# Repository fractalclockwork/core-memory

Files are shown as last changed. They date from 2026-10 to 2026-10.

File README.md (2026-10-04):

# Core Memory Driver

Electronics for driving and sensing an existing 9″ square ferrite core plane: a 64×64 array (4,096 bits / 512 bytes) with dual-readout edge connectors XA/XB and YA/YB.

Each core is **three-wire** (X, Y, sense)—there is no separate inhibit winding. Sense/inhibit is two independent 2,048-core loops (`YA65`↔`YA66` and `YB65`↔`YB66`). The driver ties `YA66` to `YB65` and reads/drives the outer ends `YA65`/`YB66`; see [docs/theory_of_operation.md](docs/theory_of_operation.md).

## Documentation

Start at [docs/README.md](docs/README.md). Frozen contracts: [docs/icd.md](docs/icd.md). Process layers L0–L4: [docs/reimplementation.md](docs/reimplementation.md). Coverage: [docs/coverage_matrix.md](docs/coverage_matrix.md).

## KiCad

Schematic and PCB live under [kicad/core/](kicad/core/). Custom symbols and card-edge footprints are in [kicad/libs/](kicad/libs/); generators are in [kicad/scripts/](kicad/scripts/). Steer fabric: `steer_64.kicad_sch` (octal tiles: [docs/hierarchy_abi.md](docs/hierarchy_abi.md)).

## Python tooling

Dependencies (e.g. [kiutils](https://pypi.org/project/kiutils/)) are managed with [uv](https://github.com/astral-sh/uv):

```bash
uv sync
uv run python kicad/scripts/gen_pipeline.py              # SPICE decks + coverage + ABI check
uv run python kicad/scripts/gen_pipeline.py --spice-only # ideal + behavioral decks only
uv run python kicad/scripts/gen_pipeline.py --kicad      # also regen KiCad sheets
uv run python kicad/scripts/gen_pipeline.py --check-abi  # octal tile pin budgets
```

Individual generators (also invoked by the pipeline `--kicad` path):

```bash
uv run python kicad/scripts/gen_xy_drive_page.py   # drive_block + steer_64
uv run python kicad/scripts/gen_xy_decode_page.py  # decode_block
uv run python kicad/scripts/gen_decoupling_pages.py
uv run python kicad/scripts/gen_ferrite_beads_page.py --array 64
uv run python kicad/scripts/gen_core_element_sim.py
```

## Simulation

```bash
kicad/core_element_sim/run_regression.sh          # L0 + L1
kicad/core_element_sim/run_regression.sh --l2     # + L2 e2e ladder
kicad/core_element_sim/run_regression.sh --ideal  # + L3 ideal n×n
```

The core-element model is exercised in [kicad/core_element_sim/](kicad/core_element_sim/). L0 detailed MCE and L3 `ideal_core` are separate — see [docs/core_element_sim.md](docs/core_element_sim.md).

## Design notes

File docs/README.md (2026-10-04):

# Design Documentation

Driver-board documentation for the 64×64 magnetic core plane.

## Reading order

1. [Interface control document (ICD)](icd.md) — frozen plane / CCS / enable contract
2. [Reimplementation process (L0–L4)](reimplementation.md) — single core → ideal n×n → fabric
3. [Coverage matrix](coverage_matrix.md) — schematic vs SPICE vs SIL vs bench (do not conflate)
4. [Hierarchical fabric ABI](hierarchy_abi.md) — steer/magnetic pin budgets and octal tiles
5. [Design review](design_review.md) — process retrospective
6. [Signal naming](naming.md) — net taxonomy, block ABI, hierarchy scale path
7. [Theory of operation](theory_of_operation.md) — how a bit is read and written
8. [Major regions](regions.md) — functional circuit blocks on the schematic
9. [Implementation summary](implementation_summary.md) — present schematic state + parts used
10. [Design choices](design_choices.md) — architecture rationale and open decisions
11. [Component selection](component_selection.md) — parts and why they were chosen
12. [Design specification](design_spec.md) — normative plane / connector / timing contract
13. [References](references.md) — bibliography and image sources

## Core element model

[Core-element simulation](core_element_sim.md) — L0 `coremem`, L1/L2 2×2 ladder, L3 `ideal_core` n×n. Regression: `kicad/core_element_sim/run_regression.sh`. Pipeline: `uv run python kicad/scripts/gen_pipeline.py`.

## Archives

- [Chip datasheets](datasheets/README.md) — offline PDF vault for selected MPNs
- [App notes](appnotes/) — supporting application notes (e.g. LTC AN13)
- [Images](img/) — photos and annotations of the physical core plane

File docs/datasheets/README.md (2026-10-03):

# Chip Datasheet Archive

Local manufacturer (or distributor-mirror) PDFs for parts used or selected in this design. Prefer these copies for offline work; verify against the vendor site before production spins.

**Policy:** PDFs are archived for private/lab design reference. Check manufacturer redistribution terms before publishing this repository widely.

Related app notes (not chip datasheets): [../appnotes/](../appnotes/).

## Index

| MPN | File | Used in | Source URL | Retrieved |
|-----|---|---|---|---|
| TLV3501 | [tlv3501.pdf](tlv3501.pdf) | Sense comparator | https://www.ti.com/lit/ds/symlink/tlv3501.pdf | 2026-10-02 |
| OPA192 | [opa192.pdf](opa192.pdf) | CCS feedback amp | https://www.ti.com/lit/ds/symlink/opa192.pdf | 2026-10-02 |
| TL431 | [tl431.pdf](tl431.pdf) | CCS voltage reference | https://www.ti.com/lit/ds/symlink/tl431.pdf | 2026-10-02 |
| SN74AHC74 | [sn74ahc74.pdf](sn74ahc74.pdf) | Sense read latch | https://www.ti.com/lit/ds/symlink/sn74ahc74.pdf | 2026-10-02 |
| SN74AHC138 | [sn74ahc138.pdf](sn74ahc138.pdf) | Decode HS (active-low Y) | https://www.ti.com/lit/ds/symlink/sn74ahc138.pdf | 2026-10-02 |
| SN74AHC238 | [sn74ahc238.pdf](sn74ahc238.pdf) | Decode LS (active-high Y) | https://www.ti.com/lit/ds/symlink/sn74ahc238.pdf | 2026-10-02 |
| TC4427A | [tc4427a.pdf](tc4427a.pdf) | Gate drivers (all channels) | https://media.digikey.com/pdf/Data%20Sheets/Microchip%20PDFs/TC4426A,27A,28A.pdf | 2026-10-02 |
| FDS8958A | [fds8958a.pdf](fds8958a.pdf) | X/Y matrix switches | https://media.digikey.com/pdf/Data%20Sheets/Fairchild%20PDFs/FDS8958A.pdf | 2026-10-02 |
| IRLZ44N | [irlz44n.pdf](irlz44n.pdf) | CCS throttle MOSFET | https://media.digikey.com/pdf/Data%20Sheets/International%20Rectifier%20PDFs/IRLZ44N.pdf | 2026-10-02 |
| BAT54S | [bat54s.pdf](bat54s.pdf) | Sense input clamps | https://www.diodes.com/assets/Datasheets/ds11005.pdf | 2026-10-02 |
| SS14 | [ss14.pdf](ss14.pdf) | Matrix steering Schottky (Vishay SS12–SS16 family sheet) | https://www.vishay.com/docs/88746/ss12.pdf | 2026-10-02 |
| Bourns 3296 | [3296.pdf](3296.pdf) | CCS setpoint trimpot | https://www.bourns.com/docs/product-datasheets/3296.pdf | 2026-10-02 |
| 2N7002 | [2n7002.pdf](2n7002.pdf) | Diagnostic LED buffers | https://media.digikey.com/pdf/Data%20Sheets/Fairchild%20PDFs/2N7002.pdf | 2026-10-02 |
| Keystone 5000-series | [keystone_5000.pdf](keystone_5000.pdf) | Loop test points | https://www.keyelco.com/userAssets/file/M65p27.pdf | 2026-10-02 |

## Not archived

| Item | Reason |
|---|---|
| 2512 1 Ω sense resistor | Commodity passive; no useful IC datasheet |
| 0805 LEDs | Commodity passive |
| AOD4184 | Alternate to IRLZ44N; not primary CCS part |

Part roles and selection rationale: [../component_selection.md](../component_selection.md).

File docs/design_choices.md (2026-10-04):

# Design Choices

Architecture decisions and tradeoffs for the core-plane driver. Part-level picks are in [component_selection.md](component_selection.md). Net grammar, hierarchical block ABI, and the bus / Replicate Layout scale path: [naming.md](naming.md).

## Three-wire cores: no separate inhibit winding

Each core carries **X**, **Y**, and **sense** only (classic 3-wire). There is no fourth inhibit wire through the array. WRITE-0 inhibit reuses the sense path at high current; READ uses the same path as a millivolt differential. That time-multiplex forces Sense-block isolation (1 kΩ), clamps, and soft center-tap bias before Inhibit can source `YA65` and sink `YB66` into the CCS.

## Series differential sense (shared READ / inhibit loops)

The plane has two independent sense/inhibit loops (`YA65`↔`YA66` and `YB65`↔`YB66`), 2,048 cores each. The driver joins them with an external center-tap jumper **`YA66`═`YB65`** and uses the outer ends (`YA65`/`YB66`) as a differential pair. That rejects common-mode drive noise that would swamp a single-ended pickup, and it keeps a single TLV3501 and a single inhibit driver. A dedicated sense-only winding is not available on this hardware, so the driver must protect and bias this shared path for both READ (small-signal) and INHIBIT (high current).

Each loop’s DCR and inductance are half of a continuous 4,096-core weave. Wiring the loops in series presents that full-array L and DCR to the driver, so \(V_{drive}\) and the CCS current stay at \(I_c/2\).

If the series-loop noise floor is too high on the bench, the deferred alternative is to drive and sense the loops in parallel: `YA65` and `YB65` both fed from the inhibit P-FET, `YA66` and `YB66` both returned to `CCS_INH` (that sink then takes \(I_c\), and \(V_{drive}\) can be lower), plus a second TLV3501 whose output is OR’d with the first. That is not the 2×2 sim fixture or the initial 8×8 build.

## Steering diodes on the driver board

The core PCB has no discrete diodes on the drive lines. Without Schottky steering at the matrix outputs, unselected lines form sneak paths that steal current and disturb half-select margins. Diodes belong on the driver board at the matrix outputs (SS14/SS16 class), not as a plane rework.

## 8×8 half-select matrix vs 64 line drivers

Driving 64 X and 64 Y lines with one switch each would explode MOSFET and connector fan-out. Grouping each axis into 8 high-side and 8 low-side switches (with direction for READ vs WRITE) yields an 8×8 coincident-current matrix: twelve address bits total, eight 3-to-8 decoders (FWD×4 + REV×4), and a compact FDS8958A-based switch farm. Cost is more careful sequencing and mandatory steering diodes.

## Prototype 1×1 before scaling lines

Bring-up proves a full READ → STROBE → INHIBIT → WRITE cycle on the 2×2 before trusting n×n SIL. Drive is one hierarchical page [`drive_block.kicad_sch`](../kicad/core/drive_block.kicad_sch): a TC4427A (HS+LS) plus one FDS8958A, with switch-node pins `N_HS_OUT` / `N_LS_OUT`. The SS14s are on [`steer_64.kicad_sch`](../kicad/core/steer_64.kicad_sch) (octal tiles next — [hierarchy_abi.md](hierarchy_abi.md)). Decode is one hierarchical page [`decode_block.kicad_sch`](../kicad/core/decode_block.kicad_sch): one axis = 74AHC138 HS + 74AHC238 LS (`ADDR_NH/NL`, `N_HS{0..7}_n`, `N_LS{0..7}_en`; line# = 8·HS + LS). Root places four decode calls and **32** drive calls (groups 0–7, X/Y, FWD/REV). REV binds `BANK_EN`←`REV_EN_n` and remaps outs to `*r_*`. Scale gates: [reimplementation.md](reimplementation.md).

## Soft mid-bias and input clamps on sense

During inhibit, the outer ends see large excursions. BAT54S clamps dump spikes into the rails; a soft resistive bias from the center tap (`YA66`/`YB65`) to AGND keeps the comparator inputs from floating between cycles. Isolation resistors (e.g. 1 kΩ in Sense) limit clamp current into the amp (~8 mA into clamps at 12 V). This favors a modern fast comparator (TLV3501) over older ±supply parts that assumed different front-ends.

A 1:1 pulse-transformer sense front-end was considered and **deferred**: on this 3-wire plane the same fold ends carry series inhibit, so a low-DCR primary across those pins would shunt inhibit current around the cores. AC-coupling the primary would still slam inhibit edges onto the secondary and force clamps/blanking, erasing the BOM win. DC-coupled Sense stays.

## Manual TL431 + trimpot CCS

Bench bring-up needs a knob for \(I_c/2\) while probing cores of uncertain coercivity (400–800 mA full-select estimate). A TL431 reference and multi-turn 3296W divider set the OPA192 target without firmware or a DAC. A later digital setpoint (DAC or PWM + filter) can replace the trimpot once the operating current is known; the MOSFET + sense-resistor power stage stays.

## AHC logic and TC4427A level shift

The timing controller is 3.3 V (RP2040). Matrix gates need fast, hard \(V_{drive}\) edges. 74AHC138/238 accept 3.3 V inputs with short propagation delay; TC4427A dual non-inverting drivers supply ampere-class gate current from the drive rail so FDS8958A switches cleanly in tens of nanoseconds. Low-side decode uses 74AHC238 (active-high) so every gate driver can be TC4427A — TC4426A is not stocked.

FWD vs REV steering uses duplicated decoder banks gated by `FWD_EN_n` / `REV_EN_n`. That removes a mux layer and keeps fail-safe behavior native (disabled 138 → HIGH → P off; disabled 238 → LOW → N off).

## RP2040 PIO for timing

READ → strobe → inhibit → WRITE needs fixed delays on the order of hundreds of nanoseconds. Main-CPU GPIO toggling under an OS or interrupt load introduces jitter that corrupts sense windows. PIO state machines give cycle-accurate multi-pin sequences while application code runs elsewhere. Another MCU with equivalent programmable I/O could substitute; the requirement is hardware sequencing, not the Pico brand.

## Decisions still open

| Topic | Notes |
|---|---|
| Exact \(I_c\) / \(I_c/2\) setpoint | Characterize on the real plane; trimpot covers 200–400 mA half-select for now |
| \(V_{drive}\) rail voltage | Must satisfy MOSFET gate drive, diode drops, and inductive headroom; value not frozen |
| Inhibit polarity vs READ | Source is `YA65` and sink is `YB66`; whether that direction matches the core’s read polarity is still a bench question |
| Inhibit switch topology | Discrete path vs reuse of matrix/CCS resources |
| On-board vs off-board RP2040 | Pico header vs soldered MCU vs external timing pod |
| Final CCS throttle MOSFET | IRLZ44N in CCS; AOD4184 (or similar) remains a thermal/package alternate |
| Diagnostic LED set | Planned on decoder outputs and DOUT; not yet on the schematic |

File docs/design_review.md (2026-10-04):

# Design review (process retrospective)

Short record of what worked and what to change. Full process: [reimplementation.md](reimplementation.md). ICD: [icd.md](icd.md).

## Verdict

The project succeeded as a **physics-and-architecture discovery engine** through the 2×2 end-to-end ladder (three CCS sinks, series fold, address→DOUT). It struggled as a **scalable productization engine**: detailed MCE was pushed toward 64×64 before an idealized array model existed; hierarchical pin explosion at steer↔plane was discovered late; generators and docs diverged; “full plane in KiCad” was conflated with “full plane in SPICE.”

## What went well

1. **Isolated MCE** before the array — reusable ~35 mV / ~1 µs contract.
2. **Single-CCS FAIL deck** — proved coincident full-select needs three sinks.
3. **Fidelity ladder** on fixed 2×2 weave — oracle → drive → matrix → inhibit → sense → e2e → strobe.
4. **Dual-loop fold archaeology** — soft mid, series inhibit on sense ends.
5. **Drive/decode block ABI** — FETs and decoders compressed correctly.
6. **Shared weave math** — `mce_array.py` as seed of one AST for sch + sim.

## What went wrong

1. Scaled detailed `coremem` instead of introducing an **idealized core** first.
2. **Pin explosion** at 256 plane ends (320-pin steer, 258-pin magnetic) designed late.
3. **Generators evolved in place** (stage1–8 → live scripts); scale names lagged (`steer_2x2`).
4. **Docs claimed bank coverage** the sim did not exercise; schematic ≠ SPICE ≠ bench.
5. Late freeze of plane topology / core-size disclaimer.
6. Missing L/DCR, PIO SIL, decoupling in nets — n×n could only prove coincidence logic.
7. Expanded 4096-MCE schematic before L3 runtime contract existed.

## Carry forward

**Keep:** isolated MCE bench; single-CCS FAIL; block ladder on small n; CCS×3; weave AST; soft fold.

**Change:** idealized core before n>2; hierarchy for 64 lines on day one; one regen pipeline; coverage matrix; separate magnetic schematic from SPICE plant; runtime as a gate.

**Do not repeat:** 4096 detailed MCEs as scale proof; growing `steer_2x2` without rename/ABI redesign; docs implying 64×64 e2e; treating checkerboard sense as traced geography.

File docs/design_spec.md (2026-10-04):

# Magnetic Core Memory Drive and Sense Circuit: Design Specification

Normative plane interface, drive architecture, and timing contract. Narrative context: [theory_of_operation.md](theory_of_operation.md). Citation keys `[cite: 1]` / `[cite: 2]` are defined in [references.md](references.md).

## 1. Physical Parameters & Interface Specification
* **PCB Dimensions:** The magnetic core plane is constructed on a 9-inch square PCB featuring four edge connector interfaces labeled XA, XB, YA, and YB [[cite: 1](references.md#core-plane-physical-evidence)].
* **Connector Type:** Dual-readout staggered edge connector.
* **Contact Dimensions:** Pins are 0.125" wide with a 0.1875" (3/16") center-to-center pitch on each face.
* **Staggered Layout:** Odd-numbered pins are located on the top face [[cite: 1](references.md#core-plane-physical-evidence)], and even-numbered pins are located on the bottom face [[cite: 2](references.md#core-plane-physical-evidence)]. Pin 1 begins 1.3125" (1-5/16") from the right edge, offsetting the top and bottom contacts by exactly 0.0625" to maximize contact area while preventing wiper shorts during insertion.
* **Axis Connectors:**
    * **X-Axis (XA, XB):** 64 pins total. Requires a 32-position, dual-readout staggered receptacle.
    * **Y-Axis (YA, YB):** 66 pins total. Requires a 33-position, dual-readout staggered receptacle.
* **Matrix Capacity:** 64×64 bidirectional drive lines yield exactly 4,096 cores (512 bytes).
* **Pin numbering vs address:** Physical edge contacts are labeled **1–64** (drive) plus Y **65/66** (sense). Schematic and firmware address drive lines **0–63**. Mapping: physical pin \(p\) ↔ logical index \(p-1\). Pins 65/66 are **not** drive lines and are **not** part of the Drive/Decode hierarchical pin chain — see §1.1 and §2.
* **Dual sense loops:** Pins 65/66 on YA and YB are two independent loops, 2,048 cores each (`YA65`↔`YA66` and `YB65`↔`YB66`). The plane does not join them. Each loop’s DCR and inductance are half of a single weave through all 4,096 cores. The driver ties `YA66`═`YB65` (external center tap) so the series path is `YA65` → Loop A → jumper → Loop B → `YB66`. Series connection restores the full-array L and DCR. [[cite: 1](references.md#core-plane-physical-evidence), [cite: 2](references.md#core-plane-physical-evidence)]

### 1.1 Three naming layers (keep separate)

Normative net grammar, block ABI, buses, and scale path: **[naming.md](naming.md)**. Mixing physical (1–64 / Y 65–66), syntax (`XA0`…, block `N`/`n`), and semantic (drive vs sense/fold) layers is a recurring source of schematic and doc bugs. Drive Block / Decode Block hierarchical pins only cover the matrix — do not extend that chain to 65/66.

## 2. Sense and Inhibit Architecture (Pins 65 & 66)
Each core is a **three-wire** element (X, Y, sense). There is **no separate inhibit winding**; inhibit is series current on the folded sense wire, time-multiplexed with READ.
* **Two loops + external fold:** Loop A `YA65`↔`YA66`; Loop B `YB65`↔`YB66`. Driver jumper **`YA66`═`YB65`**. Outer ends: `YA65` / `YB66`. The 2×2 on Magnetic Cores is the schematic stand-in (one diagonal per loop).
* **Common-Mode Noise Rejection (Read Phase):** A high-speed differential comparator (schematic: TLV3501; see [component_selection.md](component_selection.md)) across `YA65` / `YB66` isolates the millivolt flip spike. Classic techniques: [AN13](appnotes/an13f.pdf).
* **Center-Tap Bias:** Soft-bias the center tap `YA66`/`YB65` (schematic: 10 kΩ → AGND), not a hard AGND short, so inhibit current traverses both loops into the CCS.
* **Series Inhibit Drive (Write Phase):** Source \(V_{drive}\) into `YA65` and sink `YB66` to `CCS_INH` at \(-I_c/2\), so current flows Loop A, crosses `YA66`═`YB65`, and returns through Loop B — all cores in series. A parallel-drive alternative (both loops at once, two comparators) is deferred; see [design_choices.md](design_choices.md).

## 3. Drive Architecture (64x64 Matrix)
* **Matrix Structure:** Group the 64 lines per axis into 8 rows and 8 columns. Implement 8 High-Side source switches and 8 Low-Side sink switches per axis, per direction (Forward for READ, Reverse for WRITE).
* **Address Decoding:** A 12-bit address word seamlessly maps to this geometry. 6 bits decode the X-axis (3 bits for High-Side, 3 bits for Low-Side), and 6 bits decode the Y-axis. Standard 3-to-8 line decoders (74AHC138 HS / 74AHC238 LS; see [component_selection.md](component_selection.md)) control the matrix.
* **Steering Diodes:** Because there are no discrete diodes populated on the memory plane itself [[cite: 1](references.md#core-plane-physical-evidence), [cite: 2](references.md#core-plane-physical-evidence)], fast-recovery Schottky diodes must be placed on the driver board at the output of the switch matrices to prevent back-feeding and "sneak paths" through unselected core lines.

## 4. Current Recommendations ($I_c$)
* **Coercive Current ($I_c$):** Given the 0.125-inch core diameter, expect a full-select current between 400mA and 800mA. A separate single-core study uses an explicit 50-mil toroid at the top of this current band; it does not replace this paragraph. See [core_element_sim.md](core_element_sim.md). 
* **Drive Regulation:** The half-select current ($I_c/2$) of 200mA to 400mA must be strictly regulated on each axis at once. Three copies of the same adjustable constant-current sink: `CCS_X` for the X low-side returns, `CCS_Y` for the Y low-side returns, and `CCS_INH` for the inhibit return. One shared sink splits the coincident pulse and the addressed core never sees full-select. A power op-amp driving an N-channel MOSFET, monitored by a low-ohm sense resistor, holds each path flat despite the inductive load.

## 5. Timing & Sequencing
Core memory operations require sub-microsecond, deterministic pulse sequencing. A READ destroys the data, so every access is a READ / RESTORE cycle.
1. **READ Phase:** Drive $-I_c/2$ into the target X and Y lines. 
2. **SENSE STROBE:** Wait ~150-300ns for capacitive ringing to settle, then clock the D-flip-flop connected to the differential comparator across `YA65` / `YB66`.
3. **INHIBIT Phase:** If writing/restoring a '0', drive $-I_c/2$ from `YA65` through the `YA66`═`YB65` center tap and out `YB66`.
4. **WRITE Phase:** Drive $+I_c/2$ into the target X and Y lines.

Standard software bit-banging will introduce cycle jitter that corrupts memory. Utilizing hardware-level programmable state machines—such as the PIO (Programmable I/O) blocks on an RP2040/Raspberry Pi Pico—driven by tight C or Assembly routines allows for multi-phase sub-microsecond sequence execution with absolute cycle accuracy independent of the main CPU clock.

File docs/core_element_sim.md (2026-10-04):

# Core-Element Simulation

SPICE model of one three-wire memory core. The driver schematic uses it as the MCE (magnetic core element) symbol on [magnetic_core_64x64.kicad_sch](../kicad/core/magnetic_core_64x64.kicad_sch): the same six pins as the old ferrite-bead stand-in, with the flux probe kept inside the `mce` wrapper. The 2×2 page that this model was first woven into is archived at [reference/magnetic_core_2x2.kicad_sch](../kicad/core/reference/magnetic_core_2x2.kicad_sch). This project remains the isolated testbench.

KiCad project: [kicad/core_element_sim/](../kicad/core_element_sim/). Subcircuit: [models/coremem.cir](../kicad/core_element_sim/models/coremem.cir). Batch deck: [models/coremem_tb.cir](../kicad/core_element_sim/models/coremem_tb.cir).

## Why this is not the LTspice Chan `K` statement

KiCad simulates with ngspice. In that engine a `K` line is a linear coupling coefficient. It does not accept the Chan parameters `Hc`, `Br`, `Bs`, `Lm`, and `A` that LTspice puts on a mutual inductor (Chan et al., IEEE Trans. CAD, 1991; see [references.md](references.md)).

Two further limits pushed the model off that formulation:

- Memory squareness here is \(B_r/B_s = 0.18/0.20 = 0.90\). LTspice’s Chan solver is known to stall when that ratio is much above about \(2/3\), especially under one-sided saturation.
- A 20–50 mV sense pulse across a 10–50 Ω damper is only a couple of milliamps. With ideal current sources that resistor does not stretch the flip out to 1 µs. The peaking time is a parameter of the core, `Tsw`.

The subcircuit still takes the same physical numbers. Switching is a domain-wall time: while \(|H| > H_c\), the normalized remanence \(m\) slews toward the driven rail in about `Tsw`, and each winding voltage is Faraday’s law, \(V = A\,dB/dt\), with \(B = B_r m + \mu_0 \mu_r H\) clamped to \(\pm B_s\).

## Geometry and material (50-mil toroid)

This run uses a typical vintage 50-mil core, not the 0.125 in diameter inferred in [design_spec.md](design_spec.md) §4 from the edge-contact width. The plane’s normative full-select band (400–800 mA) is unchanged. The half-select used below, 400 mA, is the top of that band and is the current the coercivity was matched to.

| Quantity | Value | Origin |
|---|---|---|
| Outer / inner diameter | 1.27 mm / 0.76 mm | 50-mil toroid |
| Mean diameter | 1.0 mm | average of OD and ID |
| Magnetic path \(L_m\) | 0.00314 m | \(\pi \times 1.0\,\mathrm{mm}\) |
| Wall × height | 0.255 mm × 0.38 mm | \((OD-ID)/2\), typical height |
| Area \(A\) | \(0.097\times 10^{-6}\,\mathrm{m}^2\) | wall × height |
| \(B_s\), \(B_r\) | 0.20 T, 0.18 T | squareness \(B_r/B_s = 0.90\) |
| \(H_c\) | 150 A/m (about 1.9 Oe) | below full-select, above half-select |
| Turns | 1 on X, Y, and sense | three-wire core |
| `Tsw` | 1 µs | full-select peaking time |
| \(\mu_r\) | 20 | reversible permeability for the disturb |

Ampere’s law on one turn, \(H = I/L_m\):

- Half-select, 400 mA on X only: \(H \approx 127\,\mathrm{A/m}\), under \(H_c\). The core stays at \(+B_r\).
- Full-select, 400 mA on X and on Y: \(H \approx 255\,\mathrm{A/m}\), over \(H_c\). The core flips.

A remanence reversal \(\Delta B = 2 B_r\) through area \(A\) in 1 µs is an average sense voltage of about 35 mV, inside the 20–50 mV band expected for a single core with one sense turn.

## Stimulus

One 18 µs transient, 100 ns edges, X2/Y2/S2 grounded, 20 Ω across X and across Y. The core starts at \(m = +1\) (`tran … uic`).

| Window | Drive | Intended result |
|---|---|---|
| 2–4 µs | \(I_x = -400\,\mathrm{mA}\) | half-select disturb |
| 6–8 µs | \(I_x = I_y = -400\,\mathrm{mA}\) | read 1, \(+B_r \to -B_r\) |
| 10–12 µs | same full-select again | read 0, already at \(-B_r\) |
| 14–16 µs | \(I_x = I_y = +400\,\mathrm{mA}\) | restore to \(+B_r\) |

Open [core_element_sim.kicad_pro](../kicad/core_element_sim/core_element_sim.kicad_pro) and run the simulator; the sheet carries `.tran 20n 18u uic`. Plot `V(S1)` and `V(B)` (1 V on `B` is 1 T). The same deck from the shell:

```bash
ngspice -b kicad/core_element_sim/models/coremem_tb.cir   # RESULT PASS or RESULT FAIL
python3 kicad/core_element_sim/plot_response.py           # plots/coremem_response.png
```

`ngspice` the program is optional. The plot script talks to `libngspice`, which is the library KiCad already uses. Regenerate the sheet with `uv run python kicad/scripts/gen_core_element_sim.py`.

## Comparison with the literature

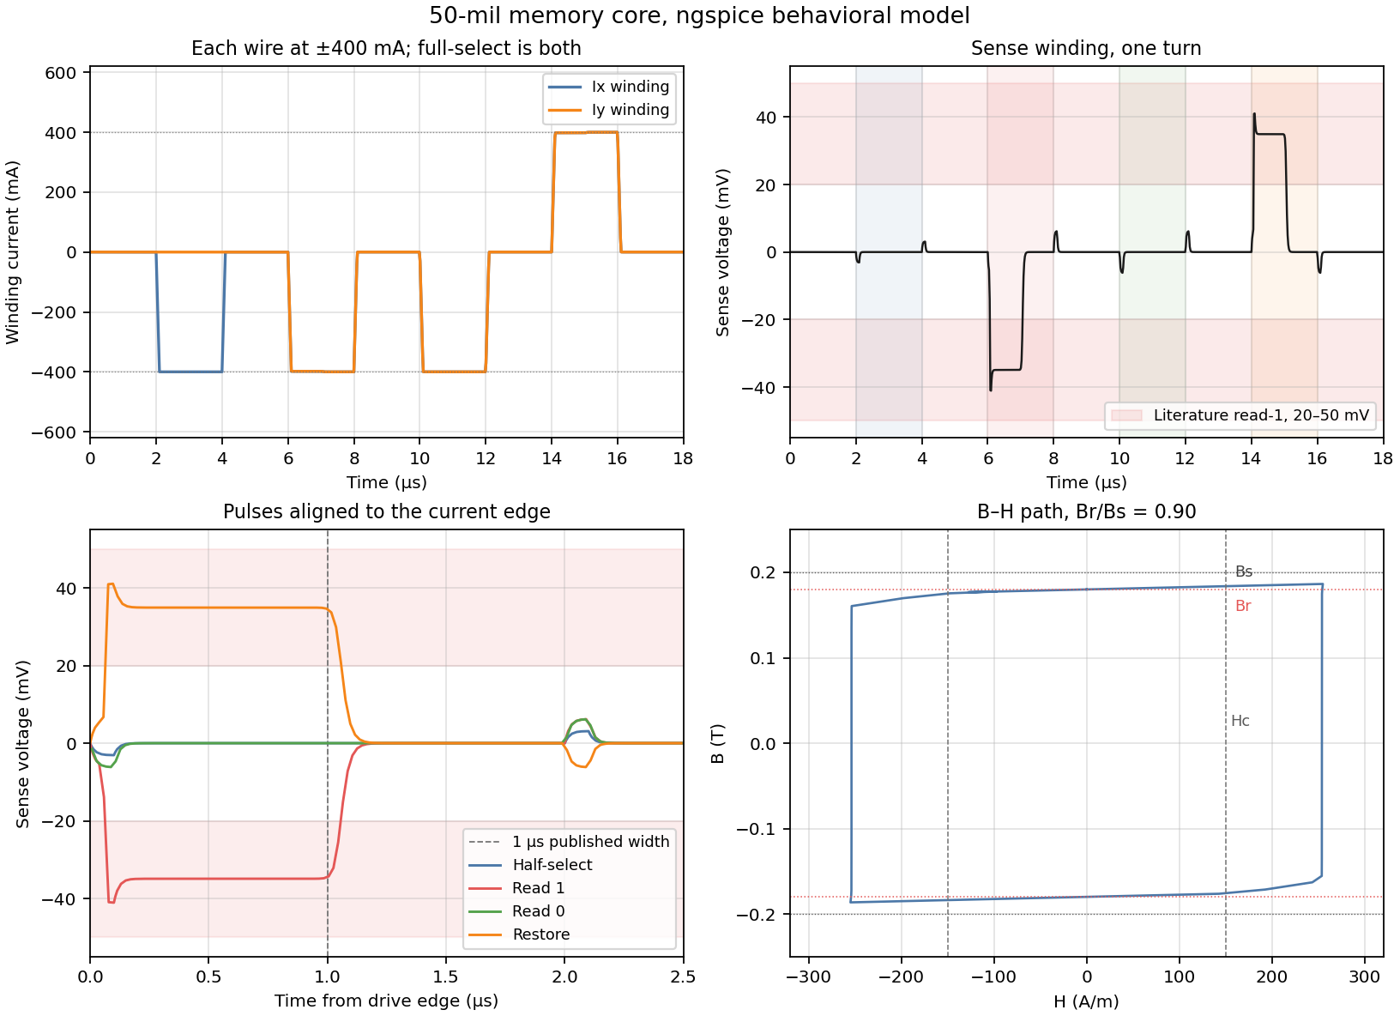
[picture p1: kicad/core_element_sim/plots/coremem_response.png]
Drive, sense, aligned pulses, and B–H path for one 50-mil core.


The pink band on the sense plots is 20–50 mV. The dashed line on the aligned pulses is 1 µs. Both are the single-core targets used to size this model (one sense turn), in the same range as the millivolt, microsecond sense signals of coincident-current practice (Forrester 1951; Papian 1952; Rajchman 1953). They are not a trace digitized from a particular oscilloscope photo.

Numbers from the plot above:

| Event | Sense peak | Width at half amplitude | Remanence after the pulse |
|---|---|---|---|
| Half-select | −3.1 mV | 0.11 µs | stays \(+B_r\) (\(m \approx +1\)) |
| Read 1 | −41 mV | 1.01 µs | flips to \(-B_r\) |
| Read 0 | −6.2 mV | 0.12 µs | stays \(-B_r\) |
| Restore | +41 mV | 1.02 µs | returns to \(+B_r\) |

What lines up with the classic behavior:

- Only the intersection flips. Half-select field stays under \(H_c\), and a second full-select in the same direction does not flip the core again (Rajchman; Papian).
- The read-1 and the restore are tens of millivolts and about 1 µs wide. The read-0 and the half-select disturb are several times smaller, which is the discrimination a sense amplifier needs.
- The B–H path is square, with \(B_r/B_s = 0.90\). \(H_c = 150\,\mathrm{A/m}\) is about 1.9 Oe, in the range memory ferrites were specified in.

Where the waveform is not a scope photo:

Published read-1 pulses are bell-shaped. Menyuk and Goodenough (1955) describe flux reversal whose rate peaks in the middle of the switch, because that is when the domain-wall area is largest. This model slews \(m\) at a nearly constant rate once \(|H| > H_c\), so \(dB/dt\) is flat for about 1 µs. The spikes at the start and end of each current edge are the reversible term \(\mu_0 \mu_r dH/dt\), not the flip. The 20 Ω dampers are on the testbench, as in the original damping note; at these sense voltages they do not set the 1 µs width.

The read-1 peak (−41 mV) is the ~35 mV remanence reversal plus the reversible edge at the start of the ramp. Polarity follows the drive: negative current produces a negative read-1; the restore is the opposite spike.

## 2×2 addressing

The archived 2×2 sheet places four of these cores in the plane’s weave: YA loop through MCE11 and MCE00 (mirrored, top-left to bottom-right), YB loop through MCE10 and MCE01, ends at the XB end of each Y edge, fold `YA66`═`YB65`. The batch deck uses that netlist after the sheet’s `Sim.Pins` map, so current XA→XB and YA→YB both add to H, and current YA65→YB66 opposes a positive write. The live sheet is that weave on a 64×64: `(x+y)` even on YA, odd on YB, 2,048 cores in each loop.

This deck is the single-sink record. The return is one copy of the schematic CCS (`models/ccs.cir`): TL431 at 2.5 V, the 10 kΩ pot set for 400 mA, OPA192, IRLZ44N, and the 1 Ω sense resistor. Selected ends are switched from a 12 V testbench rail; the other end of each driven line, and the inhibit sink, all return through that one node. The schematic does not: X, Y, and inhibit each have their own sink. In the model the op-amp output is held at 2.39 V, just above the gate that regulates 400 mA, so an open return does not wind the MOSFET up to the +5 V rail between pulses.

```bash
ngspice -b kicad/core_element_sim/models/array2x2_tb.cir   # RESULT PASS or RESULT FAIL
python3 kicad/core_element_sim/plot_array.py              # plots/array2x2_response.png
```

One 46 µs transient, cores starting at \(m=+1\). Each pulse is a 1 µs rise, a 2 µs flat, and a 1 µs fall. Read polarity sinks the A end (current B→A). Write sinks the B end. The last window is a write of X1/Y0 with inhibit current also returned through the CCS.

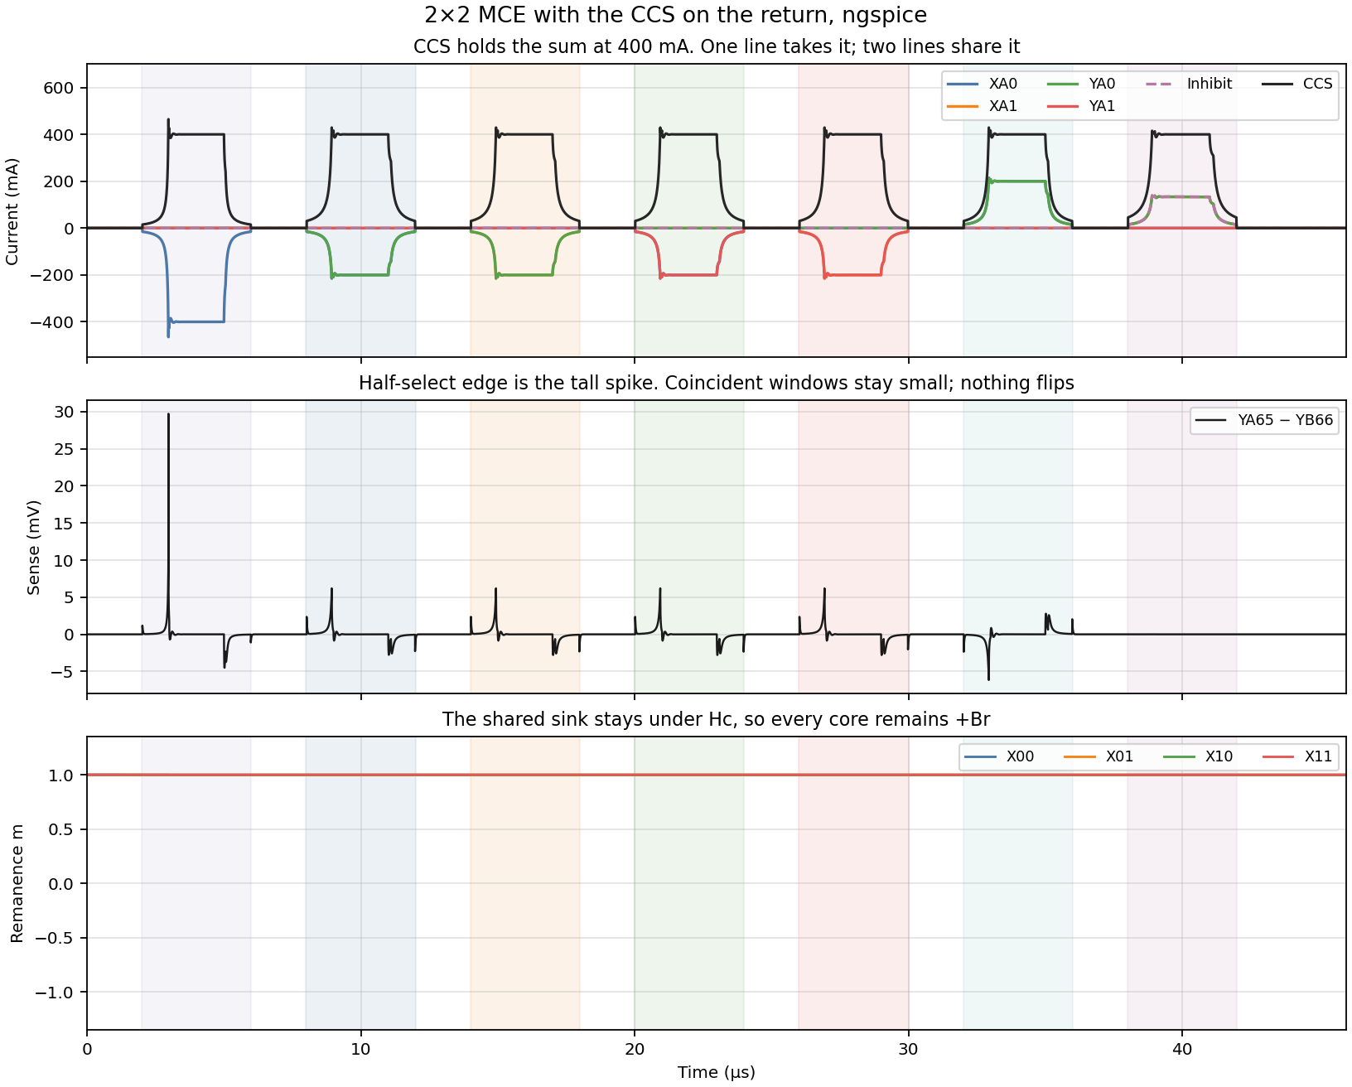
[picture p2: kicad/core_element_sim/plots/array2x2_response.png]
Line currents, series sense, and remanence of the four cores.


What the run checks:

- The sink holds 400 mA on every flat top. A single line carries that whole current. Two lines split it, about 200 mA each. Inhibit is a third path, about 134 mA, and the sum is still 400 mA.
- That split stays under \(H_c\). Half-select, every address window, the restore, and the inhibited write all leave every core at \(+B_r\).
- The half-select edge is a reversible spike of about 30 mV on `YA65`−`YB66`, from the single line taking the full 400 mA. Coincident windows are a few millivolts. Nothing on this string is a flip.

## Read / write-back

One shared sink cannot put 400 mA on X and 400 mA on Y together, so a read cannot flip the addressed core. `array2x2_cycle_tb.cir` keeps the same CCS circuit and gives the X lines, the Y lines, and the inhibit path each their own copy, every one set to 400 mA. That is the schematic: root sheets CCS X, CCS Y, and CCS INH.

All four cores start at \(-B_r\). The run visits X00, then X01, then X10, then X11. Each pulse is a 1 µs rise, a 2 µs flat, and a 1 µs fall. X and Y each have one CCS, shared by the two lines of that axis, and only one of those lines is on at a time. Inhibit has its own CCS.

```bash
ngspice -b kicad/core_element_sim/models/array2x2_cycle_tb.cir   # RESULT PASS or RESULT FAIL
python3 kicad/core_element_sim/plot_cycle.py                     # plots/array2x2_cycle.png
```

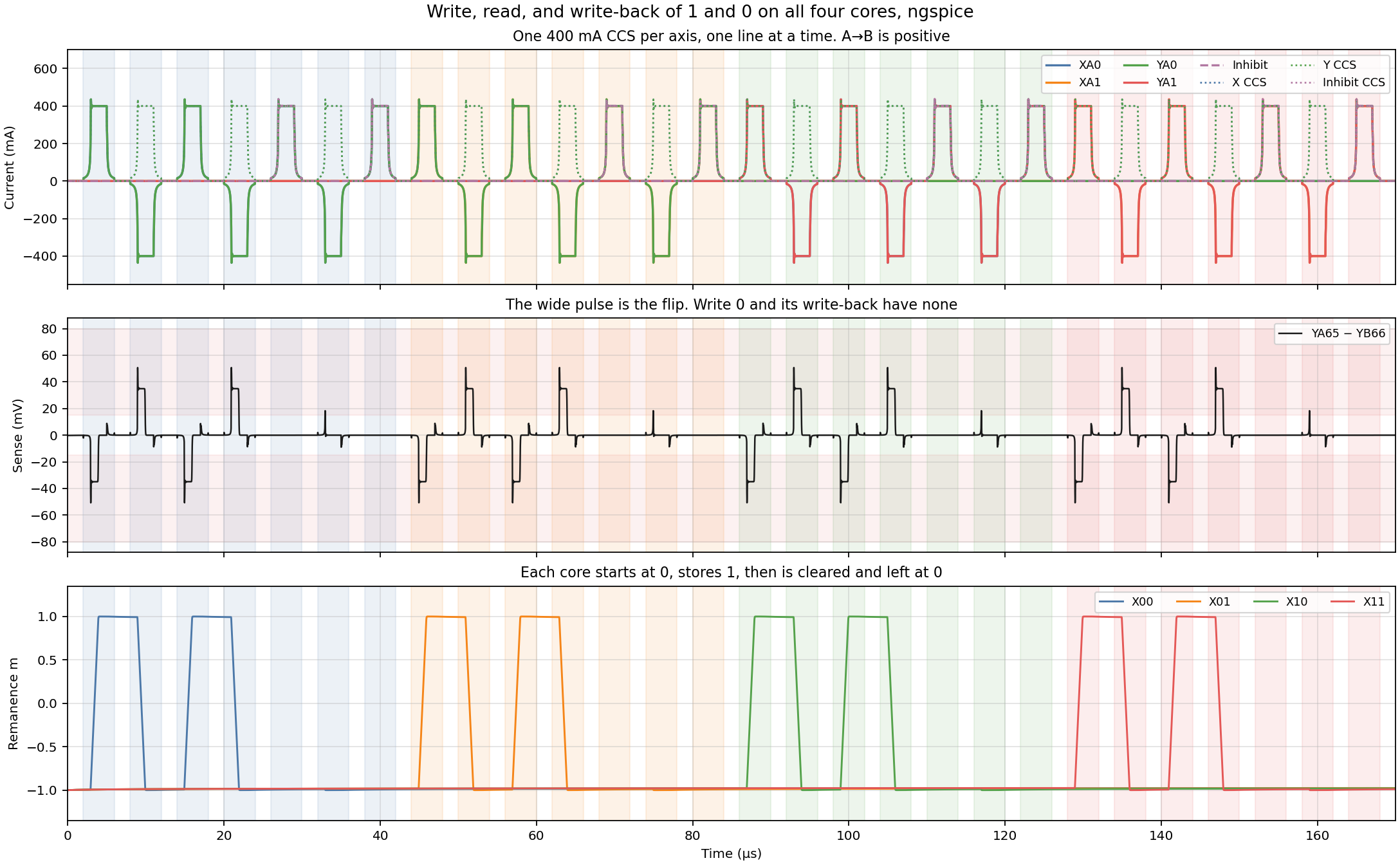
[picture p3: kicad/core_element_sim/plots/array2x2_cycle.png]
Write, read, and write-back of a 1, then of a 0, on all four cores.


What the run checks, on every core:

- Write 1 drives +400 mA on that core’s X line and Y line. The core goes to \(+B_r\). The sense plateau is about −35 mV. The other three cores stay at \(-B_r\).
- Read drives −400 mA on the same two lines. The core goes to \(-B_r\), and the plateau is about +35 mV.
- Write-back drives +400 mA again. The core returns to \(+B_r\).
- Storing a 0 starts with that same read, which clears the 1. The write then adds 400 mA inhibit on YA65→YB66, so the core stays at \(-B_r\) and the plateau collapses. Inhibit current also threads the other three cores and does not flip them.
- Read of that 0 leaves the core at \(-B_r\). The reversible edge is still there; the flip plateau is not. Write-back of the 0 is the inhibited write again, and the core stays at \(-B_r\).

The same cycle is re-run with the real blocks in place of the ideal switches. `array2x2_drive_tb.cir` puts one `drvleg` on X0. `array2x2_matrix_tb.cir` is the diode matrix (shared group-0 high side, low side selects the line). `array2x2_inhibit_tb.cir` and `array2x2_sense_tb.cir` add inhibit and the sense latch. `array2x2_e2e_tb.cir` starts from `ADDR_*`, `DEC_EN`, `FWD_EN_n`, `REV_EN_n`, `INH_EN_n`, and `SENSE_STROBE`.

```bash
ngspice -b kicad/core_element_sim/models/array2x2_e2e_tb.cir   # RESULT PASS or RESULT FAIL
python3 kicad/core_element_sim/plot_e2e.py                     # plots/array2x2_e2e.png
```

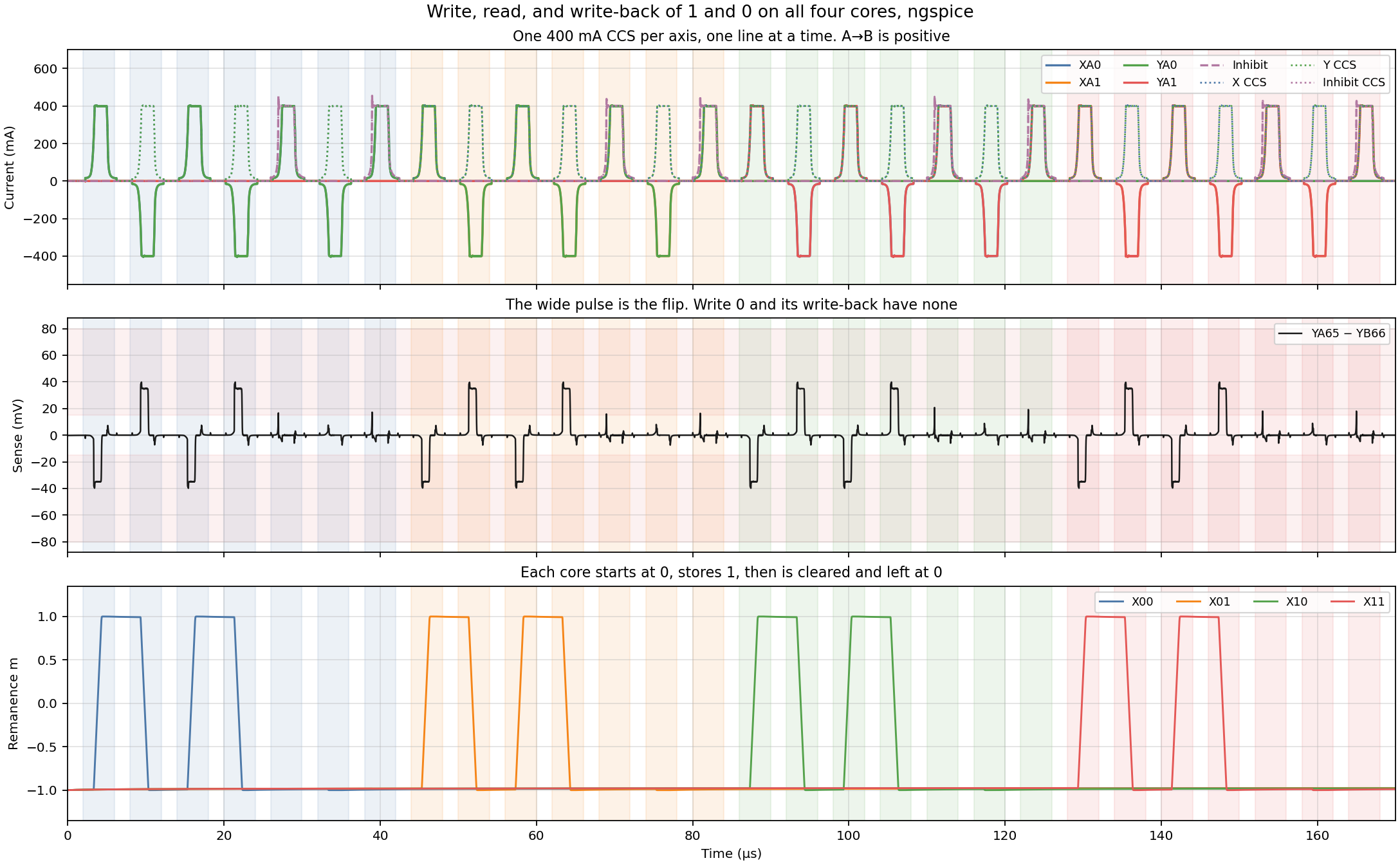
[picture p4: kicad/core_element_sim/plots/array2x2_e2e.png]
The same cycle, started from the address pins.


## 64×64 diagonal smoke

### L3 idealized (scale gate)

`array64x64_ideal_tb.cir` uses [`ideal_core.cir`](../kicad/core_element_sim/models/ideal_core.cir) (`ideal_mce`) with the same sparse diagonal plant (128 cores) but **one continuous** 0…63 write-1 transient. That is the n×n scale gate. A smaller `array_ideal_nxn_tb.cir` (n=8) is for fast SIL loops. Regenerate both with `uv run python kicad/scripts/gen_pipeline.py --spice-only`.

```bash
ngspice -b kicad/core_element_sim/models/ideal_core_tb.cir      # single ideal_core
ngspice -b kicad/core_element_sim/models/array_ideal_nxn_tb.cir
ngspice -b kicad/core_element_sim/models/array64x64_ideal_tb.cir
kicad/core_element_sim/run_regression.sh --ideal
```

### Behavioral characterization (not the L3 gate)

`array64x64_cycle.sh` runs two decks that share the live weave's pin map. Lines are 0-based, so the main diagonal is X0/Y0 through X63/Y63. There is no X64. Each of those 64 addresses gets one write 1. Both decks instance those 64 cores and one X half-select neighbor per address (128 `mce` devices), series-connected on the lines they share, with the same three 400 mA CCS copies. The other cores stay on the schematic. `array64x64_cycle_tb.cir` pulses X0/Y0 through X31/Y31. `array64x64_cycle_hi.cir` pulses X32/Y32 through X63/Y63 and starts the lower diagonal at \(+B_r\), the state those writes leave behind. One continuous transient of all 64 pulses of the **behavioral** `coremem` does not finish in a reasonable time — that is why L3 uses `ideal_mce`. The addressed core must reach about \(+B_r\). The next diagonal core, and that half-select neighbor, must stay at \(-B_r\). A core written earlier on the diagonal must stay high. Sense is the early flat (about −35 mV). X and Y sit near +400 mA.

```bash
kicad/core_element_sim/models/array64x64_cycle.sh   # RESULT PASS or RESULT FAIL
```

## What each deck includes

The 2×2 decks each have four `mce` cores, the fold, and the 10 kΩ center tap. `array2x2_tb.cir` is the one-sink record. Every other array deck instances the CCS subcircuit three times. The 64×64 **behavioral** diagonal smoke is the pair `array64x64_cycle_tb.cir` and `array64x64_cycle_hi.cir`. L3 scale decks use `ideal_mce`.

| Deck | Beyond cores and the CCS copies |
|---|---|
| `ideal_core_tb.cir` | Single L3 ideal_core half-select / flip / restore |
| `array_ideal_nxn_tb.cir` | L3 ideal diagonal, n=8, one transient |
| `array64x64_ideal_tb.cir` | L3 ideal diagonal, n=64, one transient |
| `array64x64_cycle_tb.cir` | Behavioral smoke, X0/Y0 … X31/Y31. 128 `mce`. |
| `array64x64_cycle_hi.cir` | Behavioral smoke, X32/Y32 … X63/Y63. Lower diagonal starts at \(+B_r\). |
| `array2x2_tb.cir` | One CCS. Ideal line switches. |
| `array2x2_cycle_tb.cir` | Three CCS copies. Ideal line switches. Oracle for remanence, ±400 mA, and the sense plateau. |
| `array2x2_drive_tb.cir` | `drive.cir` on the X0 pair. Other switches stay ideal. |
| `array2x2_matrix_tb.cir` | `drive.cir` on all eight half-bridges, diode steering. |
| `array2x2_inhibit_tb.cir` | Matrix, plus `inhibit.cir` returned to `CCS_INH`. |
| `array2x2_sense_tb.cir` | Inhibit deck, plus `sense.cir` and `DOUT`. |
| `array2x2_e2e_tb.cir` | Sense deck, plus `decode.cir`. Stimulus is the address and enable pins. |

`array2x2_e2e_tb.cir` also has the Decode CTRL pulls: 10 kΩ down on `DEC_EN`, 10 kΩ up on `FWD_EN_n` and `REV_EN_n`. After the cycle the sources open. The pulls hold every gate off, and `DOUT` stays low. During an X0 read, `X_HS2_n` and `Y_HS7_n` stay high and `X_LS2_en` / `Y_LS7_en` stay low, so the groups the 2×2 address does not use stay off.

`array2x2_strobe_tb.cir` is that deck with the sheet sense front-end: 1 kΩ, the clamps, the comparator, and the latch. The strobe is 300 ns into the flat. 200 ns and 250 ns do not latch a logic 1. A following X-only half-select does not latch a 1.

`array2x2_z_tb.cir` inserts one series R and one series L on each drive line and on the sense string. The default is 1 µΩ and 1 pH, and that run still passes. [theory_of_operation.md](theory_of_operation.md) records no numeric weave L or DCR, so there is no second run with a real plane impedance.

Still out of every netlist: the decoupling caps, and C5/C6 inside `ccs.cir`. They sit on ideal rails. The root schematic has drive groups 0–7, `steer_64` diodes for lines 0–63, an edge contact on each plane net, and an RP2040 header on the address and enable nets. L2 e2e transient remains four cores; n×n scale uses L3 ideal decks. Process layers: [reimplementation.md](reimplementation.md). Coverage: [coverage_matrix.md](coverage_matrix.md).

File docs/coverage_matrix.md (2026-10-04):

# Coverage matrix (schematic / SPICE / SIL / bench)

**Rule:** never equate 2×2 e2e with 64×64 proof. Each cell is independent. Regenerate with:

```bash
uv run python kicad/scripts/gen_coverage_matrix.py
```

Layers: [reimplementation.md](reimplementation.md). ICD: [icd.md](icd.md). Hierarchy: [hierarchy_abi.md](hierarchy_abi.md).

## Legend

| Mark | Meaning |
|---|---|
| PASS | Automated or documented gate passed |
| FAIL | Deliberate negative test (must keep failing) |
| smoke | Partial / subset / idealized |
| — | Not claimed |
| open | Known gap |

## Per-n coverage

| n | Schematic | SPICE L0/L1/L2 | SPICE L3 ideal | SIL | Bench |
|---|:---:|:---:|:---:|:---:|:-----:|
| 1 | isolated TB sheet | L0 `coremem_tb` PASS | — | — | open (Ic, polarity) |
| 2 | archived `magnetic_core_2x2` + live drive/decode | L1 oracle PASS; single-CCS FAIL*; L2 e2e PASS | — | — | open |
| 8 | — | — | `array_ideal_nxn_tb` | open | — |
| 64 | `magnetic_core_64x64` + `steer_64` + 32× drive | L0 diagonal smoke (128 cores, split decks) | `array64x64_ideal_tb` | open (PIO) | open |

## Deck gates (SPICE)

| Layer | Deck | Expected | Notes |
|---|---|---|---|
| L0 | `ideal_core_tb.cir` | PASS | Single ideal_core half-select / flip / restore |
| L0 | `coremem_tb.cir` | PASS | Half-select / read-1 / read-0 / restore |
| L1 | `array2x2_tb.cir` | FAIL* | Architecture record: single CCS must not coincident-flip |
| L1 | `array2x2_cycle_tb.cir` | PASS | Three CCS oracle |
| L2 | `array2x2_drive_tb.cir` | PASS | Real drive leg |
| L2 | `array2x2_matrix_tb.cir` | PASS | Diode matrix |
| L2 | `array2x2_inhibit_tb.cir` | PASS | Inhibit path |
| L2 | `array2x2_sense_tb.cir` | PASS | Sense FE |
| L2 | `array2x2_e2e_tb.cir` | PASS | Address-pin cycle |
| L2 | `array2x2_strobe_tb.cir` | PASS | Strobe window |
| L3 | `array_ideal_nxn_tb.cir` | PASS | Ideal cores; continuous addresses (n=8) |
| L3 | `array64x64_ideal_tb.cir` | PASS | Ideal diagonal, one transient |
| char | `array64x64_cycle.sh` | PASS | Behavioral subset; not L3 scale gate |

\* The L1 single-CCS deck prints `RESULT PASS` when it correctly demonstrates **no** coincident flip (split current). Treat that as “failure-mode recorded correctly,” not as a working coincident architecture.

## Hierarchical pin budgets (from `hierarchy_tiles`)

| Budget | Value |
|---|---:|
| Monolithic steer pins | 320 |
| Monolithic magnetic pins | 258 |
| Legacy root plane pin instances | 512 |
| Octal tile pins | 34 |
| Octal tile count | 16 |
| Octal diodes (must = 512) | 512 |
| Plane drive ends | 256 |

## Schematic coverage (live tree)

| Region | Claim | Status |
|---|---|---|
| Drive blocks | 32 calls, groups 0–7, X/Y, FWD/REV | present |
| Decode blocks | 4 calls | present |
| Steer | `steer_64`, diodes lines 0–63 | present (monolithic; octal tiles next) |
| Magnetic | 4,096 MCE on sheet | present (layout/net); SPICE scale via L3 |
| Sense / Inhibit / CCS×3 | hierarchical sheets | present |
| PIO / LEDs | firmware / indicators | not implemented |

## Open inputs (block scale confidence)

- Weave L/DCR (numeric)
- Inhibit polarity vs READ on the physical plane
- Normative Ic / Vdrive from bench
- Real sense geography (vs checkerboard model)
- Decoupling in transient netlists

## How to run

```bash
kicad/core_element_sim/run_regression.sh
kicad/core_element_sim/run_regression.sh --l2
kicad/core_element_sim/run_regression.sh --ideal
uv run python kicad/scripts/gen_pipeline.py --check-abi
```

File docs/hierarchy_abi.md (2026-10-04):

# Hierarchical fabric ABI (steer / magnetic)

**Problem this solves:** FET drive/decode were factored into small blocks, but the steer↔plane boundary exposed **256** A/B ends on both Steer (**320** hierarchical pins) and Magnetic Cores (**258** pins), with the same nets duplicated on the root (~512 pin instances). The sheet formerly named `steer_2x2` grew to lines 0–63 in place.

**Rule:** hierarchical boundaries match the manufacturing pin budget, not the 2×2 bring-up size.

## Target naming

| Artifact | Name | Role |
|---|---|---|
| Live steer fabric (legacy monolithic) | `steer_64.kicad_sch` | Renamed from `steer_2x2`; full 0…63 SS14 matrix |
| Preferred long-term | `steer_octal_{X,Y}_g{0..7}.kicad_sch` | One HS group × one axis (FWD+REV) |
| Preferred line tile | `steer_line` (optional) | One line, 4 diodes, 6 pins |
| Magnetic fabric | `magnetic_core_64x64.kicad_sch` | Generated weave; prefer bus pins on root |

## Pin budgets

| Boundary | Monolithic (legacy) | Octal tiles (target) | Line tiles (alt) |
|---|---:|---:|---:|
| Steer sheet pins | 320 (64 switch + 256 plane) | 34 per octal × 16 sheets | 6 per line × 128 |
| Magnetic sheet pins | 258 | Prefer `XA[63:0]`… buses on root | same |
| Root plane pin instances | 512 (Steer + Magnetic) | Wire buses once; tiles bind locally | same |

### Octal tile pin list (one axis, one HS group `g`)

Lines `L = 8·g + k` for `k = 0…7`.

| Pin | Count | Nets |
|-----|---:|---|
| `HS`, `HSR` | 2 | `{axis}HS{g}`, `{axis}HS{g}R` |
| `LS[0..7]`, `LSR[0..7]` | 16 | `{axis}LS{k}`, `{axis}LS{k}R` |
| `A[0..7]`, `B[0..7]` | 16 | `{axis}A{L}`, `{axis}B{L}` |
| **Total** | **34** | — |

Diode law (unchanged):

```text
FWD:  HS  → diode → B{line}
      A{line} → diode → LS{ls}
REV:  HSR → diode → A{line}
      B{line} → diode → LSR{ls}
```

Helpers: [`hierarchy_tiles.py`](../kicad/scripts/hierarchy_tiles.py).

### Line tile pin list (optional finer grain)

| Pin | Role |
|-----|---|
| `HS`, `LS`, `HSR`, `LSR` | Switch nodes for this line’s group |
| `A`, `B` | Plane ends |

Four SS14s inside. Root or octal parent binds group fan-out.

## Magnetic plane

1. **Layout / net semantics:** generated 64×64 MCE sheet from the weave AST ([`mce_array.py`](../kicad/scripts/mce_array.py)).
2. **SPICE scale proof:** use L3 [`ideal_core`](../kicad/core_element_sim/models/ideal_core.cir), not 4,096 detailed `coremem` instances.
3. **Root ABI:** prefer KiCad buses `XA[0..63]`, `XB[0..63]`, `YA[0..63]`, `YB[0..63]` plus `YA65` / `YB66`. Do not duplicate 256 hierarchical stubs on both Steer and Magnetic if a single bus vector can feed both.

Fold `YA66`═`YB65` stays **local** on the magnetic sheet (`SENSE_FOLD`); it is not a Drive/Decode hierarchical pin.

## Migration

| Step | Action |
|---|---|
| Done | Rename monolithic sheet `steer_2x2` → `steer_64`; update generators and root `Sheetfile` |
| Next | Emit octal tiles from `hierarchy_tiles` / pipeline; root places 16 tile calls |
| Later | Drop monolithic steer from the live tree; keep only as archive if needed |

## What never enters Drive/Decode

`YA65`, `YB65`, `YA66`, `YB66`, `SENSE_FOLD` — sense/fold only ([naming.md](naming.md) §8).

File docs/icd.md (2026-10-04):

# Plane Interface Control Document (ICD)

**Status:** frozen for reimplementation. Changes require an explicit ICD revision.

Normative companions: [design_spec.md](design_spec.md) (physical plane), [naming.md](naming.md) (net grammar), [hierarchy_abi.md](hierarchy_abi.md) (sheet boundaries).

## 1. Physical plane

| Item | Contract |
|---|---|
| Array | 64×64 = 4,096 three-wire cores |
| Edge connectors | XA, XB (64 contacts each); YA, YB (66 contacts each) |
| Drive contacts | Physical **1–64** ↔ logical nets `XA0`…`XA63` / `XB0`…`XB63` / `YA0`… / `YB0`… (`p ↔ n+1`) |
| Sense contacts | YA/YB physical **65**, **66** — **not** drive lines |

## 2. Dual-loop fold (sense / inhibit)

Two independent 2,048-core loops on the plane; the driver joins them.

```text
YA65 ── Loop A (2,048) ── YA66 ══ SENSE_FOLD ══ YB65 ── Loop B (2,048) ── YB66
                              │
                           10 kΩ → AGND
```

| Node | Role |
|---|---|
| `YA65`, `YB66` | Outer ends: differential READ and series inhibit |
| `YA66`═`YB65` | Driver jumper; schematic local name `SENSE_FOLD` |
| Soft mid | 10 kΩ → AGND (not hard AGND), so inhibit current continues through Loop B into `CCS_INH` |

Inhibit (write-0 / restore-0): source `VDRIVE` into `YA65`, sink `YB66` → `CCS_INH` at \(I_c/2\).

Checkerboard weave used in schematic/sim (`(x+y)` even → YA, odd → YB) is a **model topology**, not a traced plane geography.

## 3. Drive ends (2×64 + 2×64)

| Bus | Count | Meaning |
|-----|---:|---|
| `XA[0..63]` | 64 | X high-side end (A) |
| `XB[0..63]` | 64 | X low-side end (B) |
| `YA[0..63]` | 64 | Y high-side end (A) |
| `YB[0..63]` | 64 | Y low-side end (B) |
| **Total plane drive ends** | **256** | Dual-ended X and Y |

FWD/READ: source B from `VDRIVE`, sink A into that axis CCS.  
REV/WRITE: source A, sink B. Never assert FWD and REV together.

Address decode: `line = 8·HS + LS` (HS, LS ∈ 0…7) → logical 0…63.

## 4. Constant-current sinks (mandatory ×3)

| Sink | Serves | Setpoint |
|---|---|---|
| `CCS_X` | X low-side returns | \(I_c/2\) (bring-up band 200–400 mA; sim often 400 mA) |
| `CCS_Y` | Y low-side returns | same |
| `CCS_INH` | Inhibit return from `YB66` | same |

**One shared sink is forbidden for coincident full-select.** The single-CCS FAIL deck ([`array2x2_tb.cir`](../kicad/core_element_sim/models/array2x2_tb.cir)) is a permanent regression of that architecture error.

## 5. Enable and address polarity

| Net | Active | Fail-safe |
|-----|---|---|
| `DEC_EN` | high to enable decode | 10 kΩ → GND (off) |
| `FWD_EN_n` | low to enable FWD banks | 10 kΩ → +3V3 (off) |
| `REV_EN_n` | low to enable REV banks | 10 kΩ → +3V3 (off) |
| `INH_EN_n` | low to enable inhibit | inactive between pulses |
| `SENSE_STROBE` | rising edge clocks sense latch | — |
| `ADDR_{X,Y}{H,L}[2:0]` | HS/LS bank select per axis | — |

Gate net grammar: `^[XY]_(HS|LS)[0-9]{1,2}r?_(n|en)$` — see [naming.md](naming.md).

## 6. Hierarchical block ABI (silicon)

| Block | Pins (summary) | Scale |
|---|---|---|
| `drive_block` | `N_HSn`, `N_LSn`, `N_HS_OUT`, `N_LS_OUT`, `VDRIVE`, `CCS_RET` | 32 root calls (8 groups × X/Y × FWD/REV) |
| `decode_block` | `ADDR_NH/NL[2:0]`, `BANK_EN`, `DEC_EN`, `N_HS{0..7}_n`, `N_LS{0..7}_en` | 4 root calls (X/Y × FWD/REV) |
| Sense / Inhibit / CCS | See [regions.md](regions.md) | Not part of Drive/Decode pin chain |

Plane ends and steer diodes are **not** inside `drive_block`. Target fabric boundaries: [hierarchy_abi.md](hierarchy_abi.md).

## 7. What “done” means (do not conflate)

| Claim | Means |
|---|---|
| 2×2 e2e PASS | Address pins → decode → drive → sense latch on four cores |
| Idealized n×n PASS | Coincidence / inhibit / decode on idealized plant within runtime budget |
| Schematic 64-line | Generated fabric covers lines 0–63 |
| Bench | Measured \(I_c\), inhibit polarity, sense noise on the physical plane |

See [coverage_matrix.md](coverage_matrix.md).

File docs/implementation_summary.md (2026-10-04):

# Implementation Summary

Present state of the driver: hierarchical schematic under [`kicad/core/core.kicad_sch`](../kicad/core/core.kicad_sch). **Decode** and **Drive** are reusable blocks with `N`/`n` pins. Root places four decode calls (X/Y, FWD/REV) and **32** drive calls (groups 0–7 on each axis and direction). [`steer_64.kicad_sch`](../kicad/core/steer_64.kicad_sch) holds the SS14s for lines **0–63**. Coverage and scale gates: [coverage_matrix.md](coverage_matrix.md). ICD: [icd.md](icd.md).

Part rationale: [component_selection.md](component_selection.md). Architecture: [design_choices.md](design_choices.md), [regions.md](regions.md), [theory_of_operation.md](theory_of_operation.md).

## Architecture

Three-wire cores (X, Y, sense)—no separate inhibit winding. Sense/inhibit is two independent loops (`YA65`↔`YA66`, `YB65`↔`YB66`), joined on the driver at **`YA66`═`YB65`**. Outer ends `YA65`/`YB66` are shared for differential READ and series inhibit. The schematic array is the 64×64 on Magnetic Cores. Its sense checkerboard is the archived 2×2 rule scaled (one diagonal family per loop), not a traced plane weave. Drive is coincident half-select into two sinks (`CCS_X`, `CCS_Y`), with inhibit on its own sink (`CCS_INH`). Forward FET banks do READ (−Ic/2); reverse banks do WRITE (+Ic/2).

```
ADDR_XH/XL[2:0] ──┐
DEC_EN / FWD_EN_n ┼── Decode Block (N=axis, n=bank)
                  │   U11 138 + U12 238; four root calls (X/Y, FWD/REV)
                  ▼
        X_HS{0..7}_n / X_LS{0..7}_en
                  │
                  ▼
          drive_block (N=axis, n=group)
          TC4427A + FDS8958A; 32 root calls; SS14s on steer_64
                  └────────┬─────────┘
                           ▼
                 CCS_X / CCS_Y / plane
                           │
                  YA65/YB66 sense + inhibit (FDS8958A + TC4427A×2)
```

**Fail-safe:** `DEC_EN` pull-down (off); `FWD_EN_n` / `REV_EN_n` pull-up (inactive). Disabled **138** outputs HIGH → TC4427 → P-FET gates HIGH (off). Disabled **238** outputs LOW → TC4427 → N-FET gates LOW (off). HS inputs `*_n` have 10k pull-ups; LS inputs `*_en` have 10k pull-downs. Never assert both bank enables.

## Blocks on the sheet

| Block | What it does |
|---|---|
| Sense | Sheet `sense`: 1k iso, BAT54S, TLV3501 → 74AHC74 |
| Magnetic Cores | Sheet `magnetic_core_64x64`: MCE_r00_c00–MCE_r63_c63; center tap `SENSE_FOLD` (`YA66`═`YB65`). Archived 2×2: `kicad/core/reference/magnetic_core_2x2.kicad_sch` |
| CCS | Sheet `ccs` ×3 (X, Y, inhibit): TL431 + 3296W → OPA192 → IRLZ44N + 1Ω; pin `CCS_RET` |
| Drive | Sheet `drive_block`: TC4427A + FDS8958A + C30/C31; pins `N_HSn`/`N_LSn`/`N_HS_OUT`/`N_LS_OUT`; **32** root calls; SS14s on `steer_64` |
| Inhibit | Sheet `inhibit`: FDS8958A on YA65/YB66; TC4427A×2 + 2N7002 (`INH_LS_en`) |
| Decode | Sheet `decode_block`: one axis 138+238 + C19/C20; pins `N_HS{0..7}_n`/`N_LS{0..7}_en`; four root calls (X/Y × FWD/REV) |
| Decode CTRL | Sheets `decode_ctrl` / `decode_ctrl_y`: pins `ADDR_NH/NL`, `BANK_EN`, `DEC_EN`, `REV_EN_n`; root binds X/Y and `FWD_EN_n` |
| Decoupling Logic | Sheet `decoupling_logic`: +3V3 bypass (Sense/Latch). CCS +5V is on each CCS instance |
| Decoupling VDRIVE | Sheet `decoupling_vdrive`: VDRIVE 100n+1u for Inhibit TC4427s |
## Decode map (one axis on Decode Block)

On [`decode_block.kicad_sch`](../kicad/core/decode_block.kicad_sch) (X FWD shown; Y and REV are the other three calls):

| Ref | Part | Role | ADDR | Hier outs |
|-----|---|---|---|---|
| U11 | 74AHC138 | HS | `ADDR_NH[2:0]` | `N_HS0_n` … `N_HS7_n` |
| U12 | 74AHC238 | LS | `ADDR_NL[2:0]` | `N_LS0_en` … `N_LS7_en` |

**Line select:** `Nn = 8·HS + LS`. Root maps X FWD: `ADDR_NH*`←`ADDR_XH*`, `BANK_EN`←`FWD_EN_n`, outs → `X_HS*_n` / `X_LS*_en`. Headers J40–J54 live on **Decode CTRL** (X sheet also has `BANK_EN` / `DEC_EN` / `REV_EN_n`; Y sheet is `ADDR_NH/NL` only). Local +3V3 100n (C19/C20) lives on **Decode Block**.

Drive Block consumes `X_HS0_n` / `X_LS0_en` → `N_HSn` / `N_LSn`, plane `XA0`/`XB0`; local VDRIVE bypass C30/C31 on the block.

## Component selection (as used)

### Address decode and gate drive

| MPN | Role on sheet | Notes |
|-----|---|---|
| 74AHC138 | Decode HS (U11 on `decode_block`) | Active-low Y → TC4427 for P-FET HS |
| 74AHC238 | Decode LS (U12 on `decode_block`) | Active-high Y → TC4427 for N-FET LS |
| TC4427A | All gate drivers (Drive + Inhibit) | Non-inverting only — no TC4426A |

See [component_selection.md](component_selection.md) §1.

### Drive matrix

| MPN | Role on sheet | Notes |
|-----|---|---|
| FDS8958A | Drive Q10 on `drive_block`; Inhibit Q4 | One HS (P) + one LS (N) per package |
| SS14 | Steering on each matrix output | Plane has no diodes; blocks sneak paths |
| TC4427A | U20 on Drive Block (+ Inhibit×2) | Dual channels = HS+LS of that block |

### Constant-current sink / Sense

Unchanged (TL431, OPA192, IRLZ44N, TLV3501, BAT54S, 74AHC74, 1k iso). Soft mid on Magnetic Cores. DC-coupled Sense locked.

### Inhibit polarity helper

| MPN | Role | Notes |
|-----|---|---|
| 2N7002 | Q7 inverts `INH_EN_n` → `INH_LS_en` | Same FET family as diagnostic LED buffers; lets Inhibit use TC4427A on both HS and LS |

## Bench cycle

After CCS setpoint:

1. Assert `DEC_EN` and pulse `FWD_EN_n` → READ (−Ic/2 on X0/Y0)
2. SENSE STROBE → latch DOUT
3. Inhibit (`INH_EN_n`) if restoring/writing 0
4. Pulse `REV_EN_n` → WRITE (+Ic/2)

Plane hookup: all `XA*`/`XB*`/`YA*`/`YB*` 0…63 are wired through `steer_64`. Sense/inhibit outer ends are `YA65`/`YB66`; the center tap is `YA66`═`YB65` (`SENSE_FOLD`, 10 kΩ to AGND). SPICE e2e remains the 2×2 ladder unless an L3 ideal deck is run — see [coverage_matrix.md](coverage_matrix.md).

## Array model

The Magnetic Cores sheet is the schematic weave fixture (4,096 MCE). The checkerboard (even `x+y` on YA, odd on YB) is the 2×2 rule scaled; the real plane's geographic split is still untraced. Drive calls cover groups 0–7 on both axes and both directions. The steer sheet diodes lines 0–63. L3 ideal diagonal smoke writes X0/Y0 through X63/Y63 in **one** transient (`array64x64_ideal_tb.cir`). Legacy behavioral smoke remains two split decks.

- **Loop A:** `(x+y)` even, 2,048 cores, mirrored. The archived 2×2 is `YA65` ↔ MCE11 ↔ MCE00 ↔ `YA66`.
- **Loop B:** `(x+y)` odd, the other 2,048. The archived 2×2 is `YB65` ↔ MCE10 ↔ MCE01 ↔ `YB66`.
- **Center tap:** `YA66`═`YB65`, R1 10 kΩ→AGND. The plane does not join the loops.
- **Outer ends:** `YA65` / `YB66` for differential READ and series inhibit.

## Not implemented yet

- Octal steer tiles ([hierarchy_abi.md](hierarchy_abi.md)) — live fabric is still monolithic `steer_64`
- RP2040 PIO program / SIL. The root header only brings the stimulus nets out.
- Decoder / DOUT LEDs
- Bench calibration of \(I_c\), inhibit polarity, weave L/DCR

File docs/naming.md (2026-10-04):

# Signal naming and hierarchical scale path

Normative net grammar and KiCad hierarchy methodology for the core-plane driver. Physical connector contract: [design_spec.md](design_spec.md). Block map: [regions.md](regions.md).

**Rule:** the hierarchical sheet is a *function*; root wires are the *call arguments*. Define logic once; instantiate and scale with buses and layout replication.

## 1. Three naming layers

| Layer | What it is | Drive lines | Sense / fold |
|---|---|---|---|
| **Physical** | Stamped on the plane PCB | Contacts **1–64** on XA/XB/YA/YB | Y contacts **65**, **66** |
| **Syntax** | Nets / code / KiCad hierarchy | `XA0`…`XA63` (0-based); block tokens `N`/`n` | `YA65`…`YB66` — **outside** Drive/Decode sheet pins |
| **Semantic** | Function | Half-select matrix | READ pickup + inhibit fold — **not** drive lines |

Map: physical contact \(p\) ↔ logical index \(p-1\). Never invent drive net `XA64`. Never put 65/66 in the Drive/Decode pin chain.

## 2. Gate / enable nets (matrix control)

Format: `[N]_[func][n][dir]_[logic]`

| Token | Meaning | Valid values |
|---|---|---|
| `N` | Axis | `X`, `Y` |
| `func` | Hardware role | `HS` (high-side), `LS` (low-side) |
| `n` | Index | Line `0`…`63`, or decode bank `0`…`7` |
| `dir` | Drive direction | omit = FWD/READ; `r` = REV/WRITE |
| `logic` | Active level | `_n` = active-low; `_en` = active-high (always explicit; do not use a bare blank) |

**Examples (in tree today):** `X_HS0_n`, `X_LS0_en`.

**Examples (future REV):** `X_HS0r_n`, `X_LS0r_en`, `Y_HS3r_n`.

**Audit regex (gate nets):**

```text
^[XY]_(HS|LS)[0-9]{1,2}r?_(n|en)$
```

## 3. Plane drive nets

Format: `[N][end][n]`

| Token | Meaning | Values |
|---|---|---|
| `N` | Axis | `X`, `Y` |
| `end` | Connector side | `A` (HS end), `B` (LS end) |
| `n` | Logical line | `0`…`63` |

Examples: `XA0`, `XB0`, `YA17`, `YB63`. Physical contact number = \(n+1\).

## 4. Global and special nets

| Class | Nets |
|---|---|
| Enables | `FWD_EN_n`, `REV_EN_n`, `INH_EN_n`, `DEC_EN` |
| Analog / power | `VDRIVE`, `CCS_X`, `CCS_Y`, `CCS_INH`, `SENSE_P`, `SENSE_N`, `AGND`, `+3V3`, `+5V` |
| Sense / fold (not Drive/Decode hierarchy) | `YA65`, `YB65`, `YA66`, `YB66`, `SENSE_FOLD` |

Fold model: two independent loops `YA65`↔`YA66` and `YB65`↔`YB66`. The plane does not join them. Schematic center-tap node is **`SENSE_FOLD`**: `YA66` tied to `YB65`, soft ground 10 kΩ→AGND. Outer ends: `YA65` / `YB66`. See [theory_of_operation.md](theory_of_operation.md).

## 5. Hierarchical block ABI (reusable sheets)

Parent nets use §2–§4. **Inside** reusable sheets, pins stay parameterized with **`N`** (axis) and **`n`** (line or bank). Do not rename live block pins to `HS_CTRL_n` / `NODE_OUT` — the half-bridge needs **two** plane ends.

### Drive Block — [`drive_block.kicad_sch`](../kicad/core/drive_block.kicad_sch)

One TC4427A + FDS8958A + local VDRIVE bypass. The SS14s sit on [`steer_64.kicad_sch`](../kicad/core/steer_64.kicad_sch), not inside the block. Hierarchical pins:

| Pin | Role | Example parent (X0 FWD) |
|-----|---|---|
| `N_HSn` | HS gate (active-low) | `X_HS0_n` |
| `N_LSn` | LS gate (active-high) | `X_LS0_en` |
| `N_HS_OUT` | P-FET switch node | `XHS0` |
| `N_LS_OUT` | N-FET switch node | `XLS0` |
| `VDRIVE` / `CCS_RET` | Rails | `VDRIVE`; parent binds `CCS_X` or `CCS_Y` |

### Decode Block — [`decode_block.kicad_sch`](../kicad/core/decode_block.kicad_sch)

One axis: 74AHC138 HS + 74AHC238 LS. Hierarchical pins:

| Pin | Role | Example parent (X FWD) |
|-----|---|---|
| `ADDR_NH[2:0]` / `ADDR_NL[2:0]` | Bank address | `ADDR_XH*` / `ADDR_XL*` |
| `BANK_EN` / `DEC_EN` | Bank / chip enable | `FWD_EN_n` / `DEC_EN` |
| `N_HS{0..7}_n` | HS outs | `X_HS0_n` … `X_HS7_n` |
| `N_LS{0..7}_en` | LS outs | `X_LS0_en` … `X_LS7_en` |

`line# = 8·HS + LS` (logical 0…63).

### Decode CTRL — [`decode_ctrl.kicad_sch`](../kicad/core/decode_ctrl.kicad_sch)

Address and bank-enable headers. Same split as Drive and Decode: hierarchical pins are the function; root labels are the arguments. One axis of address per sheet. Enable headers exist once (they are not per-axis).

| Pin | Role | Example parent |
|-----|---|---|
| `ADDR_NH[2:0]` | HS address | `ADDR_XH*` (X sheet) / `ADDR_YH*` (Y sheet) |
| `ADDR_NL[2:0]` | LS address | `ADDR_XL*` / `ADDR_YL*` |
| `BANK_EN` | Bank enable, 10 kΩ to +3V3 | `FWD_EN_n` |
| `DEC_EN` | Chip enable, 10 kΩ to GND | `DEC_EN` |
| `REV_EN_n` | Reverse bank enable, 10 kΩ to +3V3 | `REV_EN_n` |

`BANK_EN` / `DEC_EN` / `REV_EN_n` are only on the X sheet ([`decode_ctrl.kicad_sch`](../kicad/core/decode_ctrl.kicad_sch), J40–J45 and J52–J54). The Y sheet ([`decode_ctrl_y.kicad_sch`](../kicad/core/decode_ctrl_y.kicad_sch), J46–J51) is the same address pins bound to `ADDR_Y*`, so the enable headers are not cloned.

## 6. Hierarchy as function call / instance

```mermaid
flowchart LR
  DecodeCTRL[Decode_CTRL]
  DecodeBlock[decode_block_N_n]
  DriveBlock[drive_block_N_n]
  Plane[XA_XB_YA_YB]

  DecodeCTRL -->|"ADDR_XH FWD_EN_n"| DecodeBlock
  DecodeBlock -->|"X_HS0_n X_LS0_en"| DriveBlock
  DriveBlock -->|"XA0 XB0"| Plane
```

1. **Define once** — atomic `drive_block` / `decode_block` / `decode_ctrl` with `N`/`n` hierarchical pins.
2. **Instantiate on root** — four `decode_block` calls (X/Y, FWD/REV; REV binds `BANK_EN`←`REV_EN_n` and `*r_*` outs) and 32 `drive_block` calls (groups 0–7, X and Y, FWD and REV). FWD sources B and sinks A. REV swaps those ends. `steer_64` holds the SS14s for lines 0–63 (`line = 8·HS + LS`). Decode CTRL is the X sheet (address + enables) plus a Y address sheet.
3. **Scale with buses** — when past 1×1, root may use KiCad buses such as `X_HS[0..7]_n` and `X_LS[0..7]_en` so the top sheet stays a few thick vectors instead of dozens of wires.
4. **PCB multiplier** — route and pour **one** Drive Block instance cleanly, then use the **Replicate Layout** plugin to copy placement and copper to further instances (7 more for an 8-line bank, or more toward 64). Hierarchy makes instance membership unambiguous for the plugin.

## 7. Scale roadmap

| Step | Schematic | SPICE / SIL | PCB |
|---|---|---|-----|
| Done | 4× decode_block, 32× drive_block, monolithic `steer_64` (lines 0–63) | L0–L2 on 2×2; L3 ideal n×n | Single block layout TBD |
| Next | Octal steer tiles ([hierarchy_abi.md](hierarchy_abi.md)); buses on root | PIO SIL on ideal plant | Replicate Drive Block |
| Later | Drop monolithic steer | Bench-calibrated L0/L3 | Full layout |

ICD freeze and layer contracts: [icd.md](icd.md), [reimplementation.md](reimplementation.md). Coverage: [coverage_matrix.md](coverage_matrix.md).

## 8. What never enters the Drive/Decode chain

`YA65`, `YB65`, `YA66`, `YB66`, and `SENSE_FOLD` are sense/fold only. They may appear as local labels on the Magnetic Cores sheet or as Sense/Inhibit hierarchical pins, but they are **not** drive switch nodes and are **not** decode outputs.

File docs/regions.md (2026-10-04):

# Major Regions

Functional blocks of the driver system and the core-plane interface. Normative connector geometry is in [design_spec.md](design_spec.md). Schematic ground truth: [kicad/core/core.kicad_sch](../kicad/core/core.kicad_sch).

## Block overview

```mermaid
flowchart TB
  PIO[Timing controller RP2040 PIO]
  Decode[Decode Block N/n]
  Drive[Drive Block N/n]
  CCS[CCS Ic/2 sink]
  Sense[Sense amp latch]
  Beads[Magnetic Cores MCE]
  Inhibit[Inhibit drive]
  Plane[Core plane XA/XB YA/YB]

  PIO --> Decode
  Decode --> Drive
  Drive --> Plane
  Drive --> CCS
  Plane --> Beads
  Beads --> Sense
  PIO --> Sense
  PIO --> Inhibit
  Inhibit --> Plane
  Inhibit --> CCS
```

## Region map

| Block | On sheet | Primary parts | Role |
|---|---|---|---|
| **Sense** | [`sense.kicad_sch`](../kicad/core/sense.kicad_sch) | TLV3501, BAT54S, 74AHC74, 1k iso | Differential sense across YA65/YB66; clamp; strobe latch to DOUT |
| **Magnetic Cores** | [`magnetic_core_64x64.kicad_sch`](../kicad/core/magnetic_core_64x64.kicad_sch) | MCE×4096, soft mid R1 | 64×64 plane model; checkerboard is the 2×2 rule scaled, not a traced weave |
| **CCS** | [`ccs.kicad_sch`](../kicad/core/ccs.kicad_sch) | TL431, Bourns 3296W, OPA192, IRLZ44N, 1 Ω sense | Regulated half-select return for low-side drivers |
| **Inhibit** | [`inhibit.kicad_sch`](../kicad/core/inhibit.kicad_sch) | FDS8958A, TC4427A×2, 2N7002 invert | Series \(-I_c/2\) on folded sense (YA65→fold→YB66→CCS); no 4th inhibit wire |
| **Drive** | Mid (sheet ×32) | `drive_block` | TC4427A + FDS8958A + local VDRIVE C30/C31; pins `N_*` / `N_HS_OUT`/`N_LS_OUT`; groups 0–7, both axes, FWD and REV |
| **Decode CTRL** | [`decode_ctrl.kicad_sch`](../kicad/core/decode_ctrl.kicad_sch), [`decode_ctrl_y.kicad_sch`](../kicad/core/decode_ctrl_y.kicad_sch) | J40–J54, R40–R54 | `ADDR_NH/NL` headers; X sheet also `BANK_EN` / `DEC_EN` / `REV_EN_n` |
| **Decode** | Lower (sheet ×1) | `decode_block` | One axis: 138 HS + 238 LS + local +3V3 C19/C20; pins `N_*`; root wires X FWD |
| **Decoupling Logic** | Bottom (sheet) | `decoupling_logic` | +3V3/+5V bypass (Sense, Latch, CCS) |
| **Decoupling VDRIVE** | Bottom (sheet) | `decoupling_vdrive` | VDRIVE 100n+1u for Inhibit TC4427s (U7/U8) |
| Plane connectors | Lib + footprints | CoreEdge XA/XB 64, YA/YB 66 | Dual-readout staggered card edge to the 9″ plane |
| Timing controller | Spec only | RP2040 / Pico (off-board or later) | Deterministic READ / STROBE / INHIBIT / WRITE |
| Testability | Partial | Keystone-style TPs; 2N7002 + LEDs planned | TP1 DOUT, TP2 Isense present; decoder/data LEDs not yet |

## Sense

Hierarchical page [`sense.kicad_sch`](../kicad/core/sense.kicad_sch) (root sheet **Sense**). Pins: `YA65`/`YB66` only. `SENSE_STROBE` / `DOUT` are global labels.

- Differential inputs from the series fold (1 kΩ from `YA65` into `SENSE_P`, 1 kΩ from `YB66` into `SENSE_N`)
- BAT54S clamps to protect the amp during inhibit spikes
- TLV3501 comparator → 74AHC74 clocked by SENSE STROBE

The plane model (MCE) and soft mid-bias live on **Magnetic Cores**. See [theory_of_operation.md](theory_of_operation.md) for the strobe window and [component_selection.md](component_selection.md) §4 for part rationale.

## Magnetic Cores

Hierarchical page [`magnetic_core_64x64.kicad_sch`](../kicad/core/magnetic_core_64x64.kicad_sch) (root sheet **Magnetic Cores**). Each core is an MCE: the six-pin layout of the old ferrite-bead stand-in, drawn as a diagonal toroid, with the [core-element](core_element_sim.md) SPICE model attached. The archived 2×2 is [`reference/magnetic_core_2x2.kicad_sch`](../kicad/core/reference/magnetic_core_2x2.kicad_sch).

**Drive hierarchy pins (0-based matrix only):** `XA0`…`XA63`, `XB0`…`XB63`, `YA0`…`YA63`, `YB0`…`YB63` — same semantic class as physical contacts 1–64. Lines 0–7 join the steer nets already on the root. Lines 8–63 are labeled and undriven until the 64-line banks exist.

**Sense / fold nets (not Drive/Decode hierarchy):** `YA65`, `YB65`, `YA66`, `YB66`, `SENSE_FOLD` — physical Y pins 65/66 plus the driver center tap; different function (fold + sense/inhibit). On the stand-in sheet they are local labels (and optionally exported for Sense/Inhibit), **not** an extension of the drive switch-node chain. Soft mid R1 10k→AGND at `SENSE_FOLD` (`YA66` tied to `YB65`). The plane does not shunt the loops.

64×64 MCE array. Columns `x` run `XAx`→`XBx` top to bottom. Rows `y` run `YAy`→`YBy` right to left. Sense is the 2×2 checkerboard scaled, not a traced plane weave: `(x+y)` even is the YA loop (mirrored, series along diagonals `x−y`), `(x+y)` odd is the YB loop (unmirrored, series along diagonals `x+y`). Each loop is 2,048 cores. The fold is `YA66`═`YB65`.

The archived 2×2, which this rule generalizes ([img/top.jpeg](img/top.jpeg)):

```text
        XA0              XA1
         |                |
   YB0 --● MCE00 ---- ● MCE01 -- YA0
         |                |
   YB1 --● MCE10 ---- ● MCE11 -- YA1
         |                |
        XB0              XB1
```

- **X** top→bottom: `XA0`→MCE00→MCE10→`XB0`; `XA1`→MCE01→MCE11→`XB1`
- **Y** right→left: `YA0`→MCE01→MCE00→`YB0`; `YA1`→MCE11→MCE10→`YB1`
- **Sense (two loops + external fold):**
  - Loop A, the top-left to bottom-right pass (stands in for 2,048): `YA65` ↔ MCE11 ↔ MCE00 ↔ `YA66`. Both ends leave at the YA–XB corner, beside MCE11.
  - Loop B, the bottom-left to top-right pass (the other 2,048): `YB65` ↔ MCE10 ↔ MCE01 ↔ `YB66`. Both ends leave at the YB–XB corner, beside MCE10.
  - Center tap: `YA66`═`YB65` (`SENSE_FOLD`) + R1 10k→AGND
  - Full series path: `YA65` → Loop A → fold → Loop B → `YB66`
- **Symbol:** diagonal ellipse (toroid). X1/X2 top/bot, Y1/Y2 left/right, S1/S2 on the LL→UR diagonal. **MCE00** and **MCE11** are mirrored about Y so that diagonal becomes UL→LR, matching the plane’s top-left to bottom-right sense pass. MCE01 and MCE10 stay unmirrored.

Each X/Y line pierces only the cores on its column/row. Regen: [`gen_ferrite_beads_page.py`](../kicad/scripts/gen_ferrite_beads_page.py) `--array 64`. `--phase 2` rewrites only the archived 2×2.

## CCS

Hierarchical page [`ccs.kicad_sch`](../kicad/core/ccs.kicad_sch), called three times. Pin: `CCS_RET`. Root binds **CCS X** → `CCS_X` (X drive), **CCS Y** → `CCS_Y` (Y drive), **CCS INH** → `CCS_INH` (inhibit). One shared sink cannot hold 400 mA on X and on Y at the same time; the cycle deck is the evidence. Each instance carries its own +5 V 100 nF + 1 µF.

Common low-side return through a linear MOSFET throttle. The OPA192 closes the loop around the 1 Ω sense resistor so pulse current stays at the trimpot setpoint despite inductive kick. Heat in the throttle MOSFET is expected; package choice (IRLZ44N or alternate) must allow linear-region dissipation.

## Inhibit

Hierarchical page [`inhibit.kicad_sch`](../kicad/core/inhibit.kicad_sch) (root sheet **Inhibit**). Pins: `YA65`/`YB66`, `CCS_RET`, `VDRIVE`; `INH_EN_n` via on-page header J5. Root binds `CCS_RET` to `CCS_INH`.

Reuses the series sense path (`YA65` → Loop A → `YA66`═`YB65` → Loop B → `YB66`). P-FET sources `VDRIVE` into `YA65`; N-FET sinks `YB66` to `CCS_INH`. Soft mid (Magnetic Cores) + 1 kΩ iso (Sense) keep inhibit off AGND and off `SENSE_*`. Both gate drivers are TC4427A: HS←`INH_EN_n`, LS←`INH_LS_en` (2N7002 invert). Whether this direction matches READ polarity on the real cores remains open ([design_choices.md](design_choices.md)).

## Drive Block

The sheet is a **function**; root wires are the **call arguments**. Define once with `N`/`n` pins. Root calls it 32 times: groups 0–7, X and Y, FWD and REV. The SS14s for lines 0–63 are on [`steer_64.kicad_sch`](../kicad/core/steer_64.kicad_sch). Target fabric: [hierarchy_abi.md](hierarchy_abi.md). See [naming.md](naming.md).

| Sheet | File | Contents |
|---|---|---|
| **Drive Block** | [`drive_block.kicad_sch`](../kicad/core/drive_block.kicad_sch) | One half-bridge: TC4427A (HS+LS) + FDS8958A. Pins are the switch nodes |
| **Steer 64** | [`steer_64.kicad_sch`](../kicad/core/steer_64.kicad_sch) | SS14s for lines 0–63. Group HS diode-ORs its eight lines; LS selects the line |
| Root | [`core.kicad_sch`](../kicad/core/core.kicad_sch) | 32× `drive_block` + one steer sheet |

Pin tokens: **`N`** = axis (`X`/`Y`), **`n`** = line (`0`…`63`). Hierarchical pins:

| Pin | Role |
|-----|---|
| `N_HSn` | HS gate input (active-low from 74AHC138) |
| `N_LSn` | LS gate input (active-high from 74AHC238) |
| `N_HS_OUT` | P-FET switch node (diode is on the steer sheet) |
| `N_LS_OUT` | N-FET switch node |
| `VDRIVE` / `CCS_RET` | `VDRIVE`; parent `CCS_X` or `CCS_Y` |

Parent polarity suffixes stay on the concrete nets for now. Current root map (X0 FWD):

| Block pin | Parent net |
|---|---|
| `N_HSn` | `X_HS0_n` |
| `N_LSn` | `X_LS0_en` |
| `N_HS_OUT` | `XHS0` (steer diode-ORs this to `XB0` and `XB1` on FWD) |
| `N_LS_OUT` | `XLS0` (steer returns `XA0` through this FET) |

FWD sources B and sinks A. REV swaps the ends (`XHS0R` onto `XA0`/`XA1`, `XLS0R` from `XB0`). Group-1 HS (`XHS1`, `YHS1`, and the REV copies) has no diode on the 2×2. Refs on the first instance: U20, Q10.

## Decode Block (8×8 one axis)

Same **function-call** pattern as Drive: one `decode_block` definition; root passes address/enables and receives gate nets such as `X_HS0_n` / `X_LS0_en` (taxonomy: `[N]_[HS|LS][n][r?]_(n|en)`). Buses (`X_HS[0..7]_n`, …) come when cloning past 1×1 — [naming.md](naming.md).

| Sheet | File | Contents |
|---|---|---|
| **Decode Block** | [`decode_block.kicad_sch`](../kicad/core/decode_block.kicad_sch) | One axis: 74AHC138 HS + 74AHC238 LS; all Y0–Y7 wired |
| **Decode CTRL** | [`decode_ctrl.kicad_sch`](../kicad/core/decode_ctrl.kicad_sch), [`decode_ctrl_y.kicad_sch`](../kicad/core/decode_ctrl_y.kicad_sch) | J40–J54 headers + R40–R54 fail-safe pulls. Pins `ADDR_NH/NL`; enables only on the X sheet |
| Root | [`core.kicad_sch`](../kicad/core/core.kicad_sch) | Decode CTRL (X + enables) + Decode CTRL Y + 1× `decode_block` — X FWD bring-up |

Pin tokens: **`N`** = axis (`X`/`Y`), **`n`** = HS/LS bank index (`0`…`7`). Hierarchical pins:

| Pin | Role |
|-----|---|
| `ADDR_NH[2:0]` / `ADDR_NL[2:0]` | HS / LS address into the 3-to-8s |
| `BANK_EN` / `DEC_EN` | `~E0` / `E2` ( `~E1`←GND ) |
| `N_HS{0..7}_n` | HS outs (active-low) |
| `N_LS{0..7}_en` | LS outs (active-high) |

`line# = 8·HS + LS`. Parent polarity suffixes stay on concrete nets. Current root map (X FWD):

| Block pin | Parent net |
|---|---|
| `ADDR_NH*` / `ADDR_NL*` | `ADDR_XH*` / `ADDR_XL*` |
| `BANK_EN` | `FWD_EN_n` |
| `DEC_EN` | `DEC_EN` |
| `N_HS{0..7}_n` / `N_LS{0..7}_en` | `X_HS*_n` / `X_LS*_en` |

Y / REV instances (`BANK_EN`←`REV_EN_n`, outs → `*r_*`) come later. Refs today: U11/U12.

**Bench plane map:** Drive Block still `XA0`/`XB0` only; Magnetic Cores exposes `XA0`…`XA63` and the matching XB/YA/YB lines. Sense/inhibit outer ends are `YA65`/`YB66`, center tap `YA66`═`YB65`.

## Decoupling (Logic / VDRIVE)

Per-IC bypass lives in the reusable blocks; shared rails stay on two hierarchy pages (global power nets; no hierarchical pins):

| Sheet / block | File | Rails / parts |
|---|---|---|
| **Drive Block** | [`drive_block.kicad_sch`](../kicad/core/drive_block.kicad_sch) | VDRIVE: C30 100n + C31 1u next to TC4427 |
| **Decode Block** | [`decode_block.kicad_sch`](../kicad/core/decode_block.kicad_sch) | +3V3: C19/C20 100n next to U11/U12 |
| **Decoupling Logic** | [`decoupling_logic.kicad_sch`](../kicad/core/decoupling_logic.kicad_sch) | +3V3: C1/C2 (Sense), C3/C4 (Latch). CCS +5V bypass is C5/C6 on each CCS instance |
| **Decoupling VDRIVE** | [`decoupling_vdrive.kicad_sch`](../kicad/core/decoupling_vdrive.kicad_sch) | VDRIVE: C11–C14 (Inhibit U7/U8) — each 100n+1u pair |

Regen: [`gen_decoupling_pages.py`](../kicad/scripts/gen_decoupling_pages.py) (also regenerates `drive_block` / `decode_block` and strips root caps).

**Connectors** use custom footprints sized from the plane: 32-position dual-readout for X (64 pins), 33-position for Y (66 pins). Pin stagger and first-pin offset are normative in the design spec.

## Plane interface (summary)

| Axis | Connectors | Pins | Notes |
|---|---|---|---|
| X | XA, XB | 64 | Drive lines only |
| Y | YA, YB | 66 | **1–64** drive (schematic `YA0`…`YB63`) + **65/66** sense/fold only — not part of Drive/Decode hierarchy |

Physical photos: [img/core_pcb_top.png](img/core_pcb_top.png), [img/core_pcb_bot_mirror.png](img/core_pcb_bot_mirror.png).

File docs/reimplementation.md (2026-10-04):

# Reimplementation process (L0–L4)

Ground-up path from a single core element to idealized n×n simulation-in-the-loop, then hardware fabric. Companion retrospective themes: keep the 2×2 fidelity ladder; introduce an idealized core **before** scaling past 2×2; freeze hierarchy for 64 lines early.

```mermaid
flowchart TB
  subgraph L0 [L0 Physics]
    MCE[Detailed MCE coremem]
    Lit[Literature / bench targets]
  end
  subgraph L1 [L1 Oracle 2x2]
    Weave[Real weave pin map]
    IdealDrv[Ideal drvsw + 3x CCS]
    Cycle[Write/Read/Inhibit oracle]
  end
  subgraph L2 [L2 Driver fidelity]
    Drive[drive / matrix / inhibit / sense / decode]
    E2E[Address-pin e2e]
  end
  subgraph L3 [L3 Idealized nXn]
    IdealMCE[ideal_core]
    Sparse[Sparse active cores + line Z]
    SIL[Sim-in-the-loop PIO / decode]
  end
  subgraph L4 [L4 Hardware ABI]
    Blocks[drive_block / decode_block]
    Steer[Steer octal tiles]
    Plane[Magnetic fabric]
  end
  Lit --> MCE
  MCE --> Weave
  Weave --> IdealDrv --> Cycle
  Cycle --> Drive --> E2E
  Cycle --> IdealMCE --> Sparse --> SIL
  E2E --> Blocks
  IdealMCE --> Plane
  Blocks --> Steer --> Plane
```

## Principles

1. **Fidelity is a dial per layer** — never instance detailed `coremem` at n=64 as the scale proof.
2. **One weave AST** ([`mce_array.py`](../kicad/scripts/mce_array.py)) generates SPICE, KiCad, and coverage.
3. **Hierarchical boundaries match the 256-end pin budget** — [hierarchy_abi.md](hierarchy_abi.md).
4. **Coverage tables**, not lagging narrative — [coverage_matrix.md](coverage_matrix.md).
5. **No n×n schematic fabric until L2 e2e is green and L3 meets a runtime budget.**

## Layer contracts

### L0 — Detailed single core

| Item | Contract |
|---|---|
| Model | [`coremem.cir`](../kicad/core_element_sim/models/coremem.cir) / `mce` |
| Deck | [`coremem_tb.cir`](../kicad/core_element_sim/models/coremem_tb.cir) |
| Gates | Half-select hold; read-1 ~tens of mV / ~1 µs; read-0 discrimination; restore polarity |
| Limit | Do not instance more than ~4–16 L0 cores in one transient without a runtime budget check |

### L1 — Oracle array (n=2)

| Item | Contract |
|---|---|
| Weave | Same pin map as archived 2×2 / `mce_array.assert_matches_2x2()` |
| Drive | Ideal `drvsw` + **three** CCS copies |
| Decks | [`array2x2_cycle_tb.cir`](../kicad/core_element_sim/models/array2x2_cycle_tb.cir) (PASS oracle); [`array2x2_tb.cir`](../kicad/core_element_sim/models/array2x2_tb.cir) (**FAIL** single-CCS record) |
| Gates | Remanence after write/read/inhibit; sense plateau; no half-select flips |

### L2 — Driver fidelity (still n=2)

Replace ideals one block at a time: drive → matrix → inhibit → sense → decode e2e → strobe.

| Deck | Proves |
|---|---|
| `array2x2_drive_tb` | One real `drvleg` |
| `array2x2_matrix_tb` | Diode steering |
| `array2x2_inhibit_tb` | Series inhibit + `CCS_INH` |
| `array2x2_sense_tb` | Front-end + latch |
| `array2x2_e2e_tb` | Cycle from `ADDR_*` / enables / strobe |
| `array2x2_strobe_tb` | 300 ns into flat latches |

Freeze schematic ABI here ([icd.md](icd.md) §5–§6).

### L3 — Idealized n×n + SIL

| Item | Contract |
|---|---|
| Model | [`ideal_core.cir`](../kicad/core_element_sim/models/ideal_core.cir) — threshold remanence + fixed sense injection |
| Plant | All lines present; sparse active cores (diagonal + neighbors) or O(1) behavioral sources |
| Runtime | Full diagonal or random pattern in **one** continuous run finishes in minutes |
| SIL | Same address/enable nets as L2; plant is idealized (PIO stimulus may be synthetic) |
| Gates | Coincidence only at intersection; inhibit blocks write-1; sense discrimination; decode selects the right line pair |

Do **not** use L0 `coremem` for n=64 scale proof. The legacy behavioral diagonal smoke (`array64x64_cycle_*.cir`) remains a characterization aid, not the L3 gate.

### L4 — Hardware fabric

Only after L2 green and L3 runtime OK:

- Steer as **octal tiles** (or equivalent bus ABI) — not one 320-pin sheet
- Magnetic plane from weave AST; schematic may condense while SPICE uses L3
- Sheet names match scale (`steer_64`, `steer_octal_*`)
- Regen via [`gen_pipeline.py`](../kicad/scripts/gen_pipeline.py); coverage auto-updated

## Milestones

1. ICD freeze — [icd.md](icd.md)
2. L0/L1 regression suite — `kicad/core_element_sim/run_regression.sh`
3. L2 block library — 2×2 e2e only until green
4. L3 ideal plant — `ideal_core` + ideal diagonal / n×n decks
5. L4 tiled fabric — [hierarchy_abi.md](hierarchy_abi.md)
6. Bench calibration — retune L0/L3 from measured \(I_c\), inhibit polarity, sense noise

## Regression entry point

```bash
kicad/core_element_sim/run_regression.sh          # L0 + L1 (+ optional L2)
kicad/core_element_sim/run_regression.sh --ideal  # also L3 ideal smoke
uv run python kicad/scripts/gen_pipeline.py --help
```

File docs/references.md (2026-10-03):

# References

## Core plane (physical evidence)

Citations `[cite: 1]` and `[cite: 2]` in [design_spec.md](design_spec.md) refer to inspection of the existing 9″ core PCB:

1. **Top face / primary inspection** — odd-numbered edge contacts on the top face; XA/XB/YA/YB labeling; four sense/inhibit terminals `YA65`, `YA66`, `YB65`, `YB66` (two independent 2,048-core loops; the series jumper is on the driver, not the plane). See [img/top.jpeg](img/top.jpeg), [img/core_pcb_top.png](img/core_pcb_top.png), and the annotated GIMP source [img/core_pcb.xcf](img/core_pcb.xcf).
2. **Bottom face** — even-numbered contacts on the bottom face; complementary view of the sense terminals and connector stagger. See [img/bot.jpeg](img/bot.jpeg), [img/core_pcb_bot_mirror.png](img/core_pcb_bot_mirror.png).

## Coincident-current cores

Cited from [core_element_sim.md](core_element_sim.md). The 20–50 mV and 1 µs marks on the plot are the single-core targets used to size the model, not quotations from these papers.

1. J. W. Forrester, “Digital information storage in three dimensions using magnetic cores,” *J. Appl. Phys.*, vol. 22, no. 1, pp. 44–48, Jan. 1951.
2. W. N. Papian, “A coincident-current magnetic memory cell for the storage of digital information,” *Proc. IRE*, vol. 40, no. 4, pp. 475–478, Apr. 1952.
3. J. A. Rajchman, “A myriabit magnetic-core matrix memory,” *Proc. IRE*, vol. 41, no. 10, pp. 1407–1421, Oct. 1953.
4. N. Menyuk and J. B. Goodenough, “Magnetic materials for digital-computer components. I. A theory of flux reversal in polycrystalline ferromagnetics,” *J. Appl. Phys.*, vol. 26, no. 1, pp. 8–18, Jan. 1955.
5. J. H. Chan, A. Vladimirescu, X.-C. Gao, P. Liebmann, and J. Valainis, “Nonlinear transformer model for circuit simulation,” *IEEE Trans. Computer-Aided Design*, vol. 10, no. 4, pp. 476–482, Apr. 1991.

## Application notes

| ID | Document | Archive |
|----|---|---|
| AN13 | Linear Technology AN13, *High Speed Comparator Techniques* (LT1016-era methods still relevant to sense-front-end layout and strobing) | [appnotes/an13f.pdf](appnotes/an13f.pdf) |

## Chip datasheets

Manufacturer PDFs for selected MPNs are archived under [datasheets/](datasheets/README.md). Prefer those local copies for offline work; source URLs are recorded in the datasheet index.

## Project documents

| Document | Role |
|---|---|
| [theory_of_operation.md](theory_of_operation.md) | Read/write cycle narrative |
| [regions.md](regions.md) | Functional block map |
| [design_choices.md](design_choices.md) | Architecture rationale |
| [component_selection.md](component_selection.md) | Part choices |
| [design_spec.md](design_spec.md) | Normative interface and timing |
| [core_element_sim.md](core_element_sim.md) | Single-core ngspice model and literature comparison |
| [../kicad/core/core.kicad_sch](../kicad/core/core.kicad_sch) | Schematic ground truth (functional blocks) |
| [../kicad/core_element_sim/](../kicad/core_element_sim/) | Isolated core-element KiCad project |

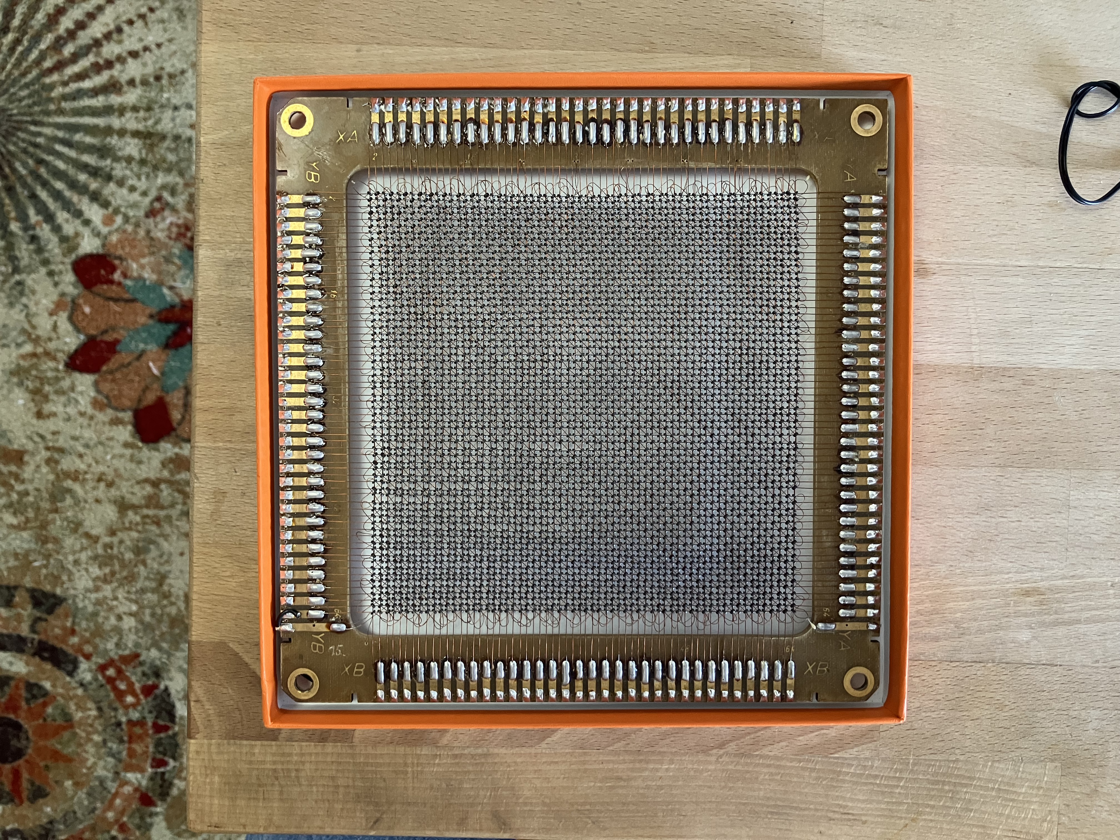
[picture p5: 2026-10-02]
docs/img/top.jpeg

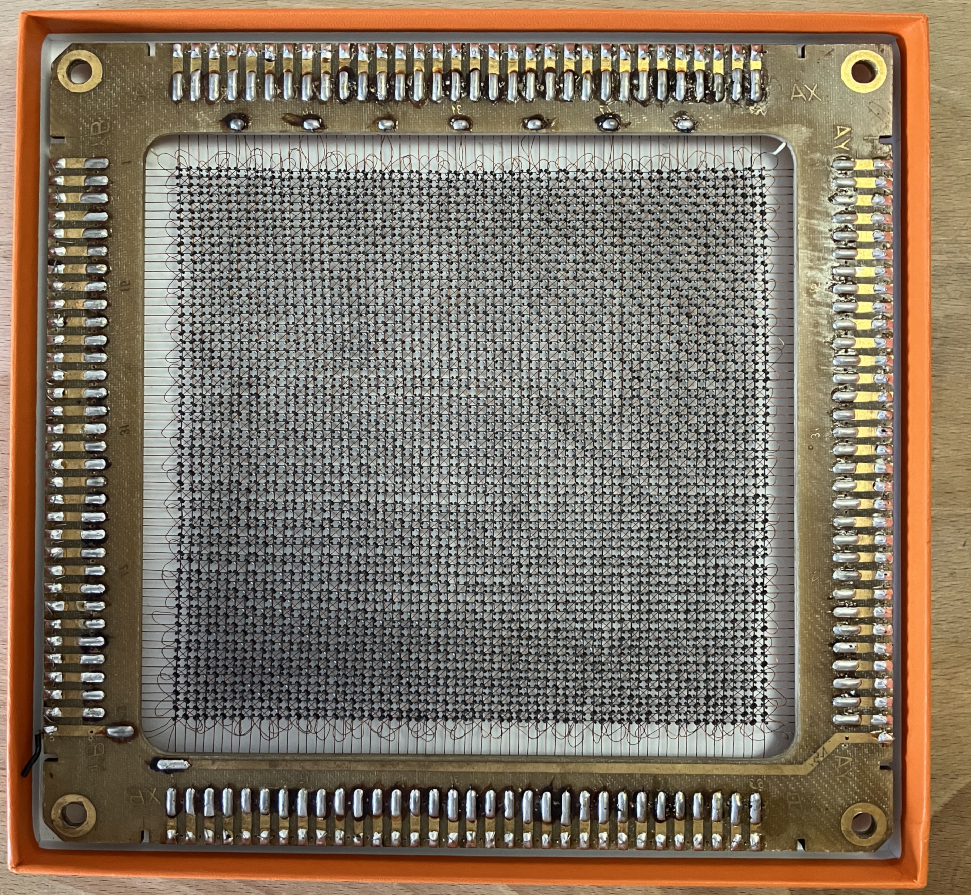
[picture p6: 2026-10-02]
docs/img/core_pcb_bot_mirror.png

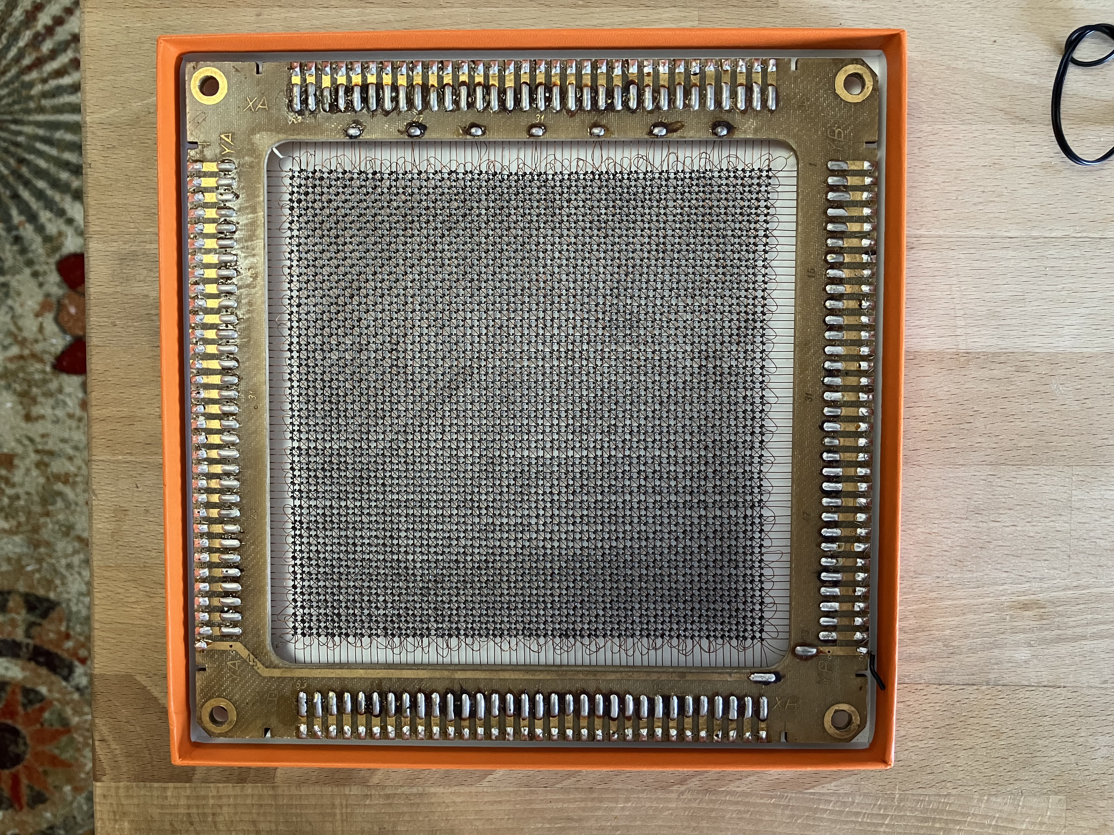
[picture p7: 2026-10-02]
docs/img/bot.jpeg

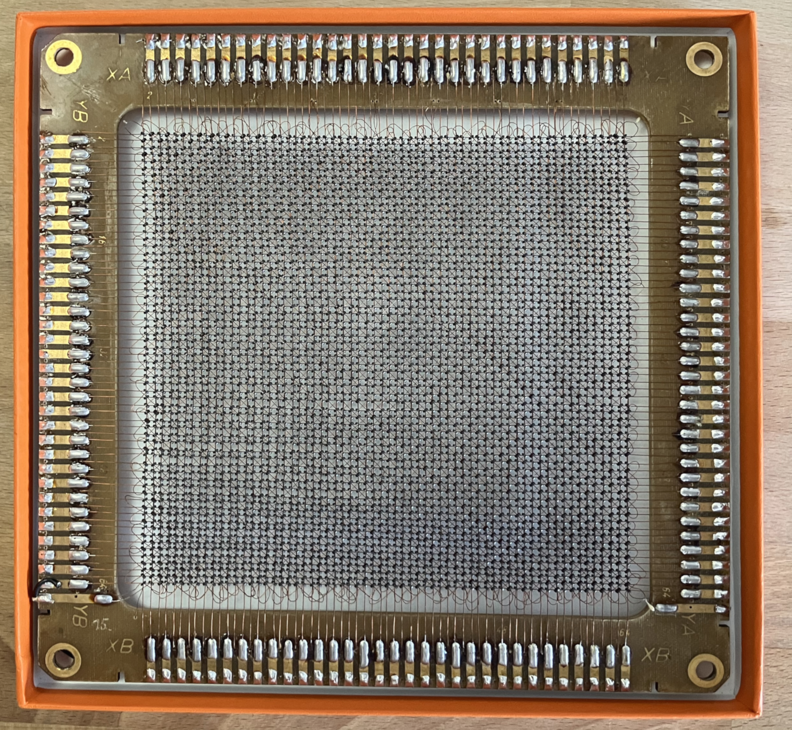
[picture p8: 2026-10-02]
docs/img/core_pcb_top.png

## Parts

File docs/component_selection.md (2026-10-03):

# Component Selection

Part choices for the core-memory driver. Architecture rationale is in [design_choices.md](design_choices.md). Offline PDFs live in [datasheets/](datasheets/README.md).

Schematic ground truth for the 1×1 prototype (functional blocks): [kicad/core/core.kicad_sch](../kicad/core/core.kicad_sch). Present wiring map: [implementation_summary.md](implementation_summary.md).

---

## 1. Address Decoding & Level Shifting

The 3.3 V logic from the timing controller must become high-current, high-voltage gate drive so the matrix MOSFETs snap open and closed cleanly.

| MPN | Role | Package | Key params | Alternate | Datasheet |
|-----|---|---|---|---|---|
| 74AHC138 | 3-to-8 decoder HS (×4: FWD/REV × X-H/Y-H) | SOIC-16 | Active-low Y0–Y7; bank enables | 74HC138 | [sn74ahc138.pdf](datasheets/sn74ahc138.pdf) |
| 74AHC238 | 3-to-8 decoder LS (×4: FWD/REV × X-L/Y-L) | SOIC-16 | Active-high Y0–Y7; same enables as 138 | 74HC238 | [sn74ahc238.pdf](datasheets/sn74ahc238.pdf) |
| TC4427A | Dual non-inverting gate driver (all channels) | SOIC-8 / DIP-8 | 1.5 A peak from \(V_{drive}\) | — (TC4426A removed) | [tc4427a.pdf](datasheets/tc4427a.pdf) |

AHC decoders accept 3.3 V inputs. **HS** uses 74AHC138 (active-low Y + TC4427 → P-FET). **LS** uses 74AHC238 (active-high Y + TC4427 → N-FET) so the board stocks only TC4427A gate drivers. Same enable wiring on both (`~E0`/`~E1`/`E2` family): bank EN, GND, `DEC_EN`. Disabled 138 → Y HIGH (P off); disabled 238 → Y LOW (N off).

**KiCad symbol vs MPN:** sheets use pin-compatible lib_id `74xx:74HC138` / `74xx:74HC238` with Value set to the ordered MPN (`74AHC138` / `74AHC238`). Do not treat the HC lib_id as the BOM part.

---

## 2. The Drive Matrix (64×64)

| MPN | Role | Package | Key params | Alternate | Datasheet |
|-----|---|---|---|---|---|
| FDS8958A | Dual N + P PowerTrench switch | SOIC-8 | One HS + one LS per package; low Rds(on) | Discrete complementary pair | [fds8958a.pdf](datasheets/fds8958a.pdf) |
| SS14 | Steering Schottky | SMA | 1 A, low Vf, fast recovery | SS16 (higher Vr) | [ss14.pdf](datasheets/ss14.pdf) |

One FDS8958A per matrix node keeps layout compact. Schottky steering at matrix outputs blocks sneak paths; the plane has no on-board diodes.

---

## 3. Constant-Current Sink (manual)

Low-side matrix returns share an adjustable CCS so \(I_c/2\) stays flat into the inductive load (target band ~200–400 mA).

| MPN | Role | Package | Key params | Alternate | Datasheet |
|-----|---|---|---|---|---|
| TL431 | Precision shunt reference | SOT-23 / TO-92 | Stable Vref for setpoint divider | TLV431 (lower Vref) | [tl431.pdf](datasheets/tl431.pdf) |
| Bourns 3296W | 10 kΩ multi-turn trimpot | 3296W | Bench adjustment of \(I_c/2\) | 3296Y (side adjust) | [3296.pdf](datasheets/3296.pdf) |
| OPA192 | Feedback error amp | SOIC-8 | 10 MHz GBW, fast slew | OPA191 | [opa192.pdf](datasheets/opa192.pdf) |
| IRLZ44N | Throttle N-MOSFET (CCS) | TO-220 / DPAK family | Linear-region dissipation | AOD4184 | [irlz44n.pdf](datasheets/irlz44n.pdf) |
| 1.0 Ω 1% 2 W | Current sense | 2512 SMD | Low inductance thick film | 0.47 Ω (if higher I) | — (no IC datasheet) |

Speed matters when the drive pulse hits: the op-amp must contain inductive overshoot within the microsecond pulse. The throttle MOSFET runs in its linear region and must handle the waste heat.

---

## 4. Sense & Inhibit Front End (pins 65 & 66)

Isolates the differential read pulse from common-mode noise and protect the amp during inhibit.

| MPN | Role | Package | Key params | Alternate | Datasheet |
|-----|---|---|---|---|---|
| BAT54S | Dual series Schottky clamp | SOT-23 | Clamp YA65/YB66 to rails | BAT54C | [bat54s.pdf](datasheets/bat54s.pdf) |
| TLV3501 | High-speed comparator (Sense) | SOT-23-5 / SOIC | 4.5 ns tpd, 3.3 V logic out | LT1016 (legacy ±5 V class) | [tlv3501.pdf](datasheets/tlv3501.pdf) |
| 74AHC74 | D flip-flop read latch | SOIC-14 | Captures comparator on SENSE STROBE | 74LVC74 | [sn74ahc74.pdf](datasheets/sn74ahc74.pdf) |

Sense uses **TLV3501** (not LT1016): single-supply 3.3 V logic-friendly output and very short propagation delay. Classic comparator layout/strobe advice remains useful — see [AN13](appnotes/an13f.pdf). The latch clocks ~150–300 ns into READ to miss capacitive ringing and catch the core flip.

---

## 5. Hardware Testability

| MPN / series | Role | Package | Key params | Alternate | Datasheet |
|---|---|---|---|---|---|
| Keystone 5000-series | Loop test points | Through-hole loop | SENSE STROBE, DOUT, Isense | Equivalent loop TP | [keystone_5000.pdf](datasheets/keystone_5000.pdf) |
| 2N7002 | LED buffer N-MOSFET | SOT-23 | Decoder / DOUT indicators | 2N7002K | [2n7002.pdf](datasheets/2n7002.pdf) |
| 0805 LED | Diagnostic indicators | 0805 | Address + data visibility | — | — |

Populate loop-style test points on SENSE STROBE, the sense-latch output, and the top of the current-sense resistor (TP1 DOUT and TP2 Isense are already on Sense / CCS). Route decoder and latched data through small N-FETs to 0805 LEDs for step debugging before full-speed PIO cycles.

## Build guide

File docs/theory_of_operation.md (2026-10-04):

# Theory of Operation

How the driver board reads and writes a single bit on the 64×64 ferrite core plane.

## Core physics (brief)

Each ferrite core stores one bit as magnetic remanence in one of two directions. A full-select current \(I_c\) through a core flips its state; half-select \(I_c/2\) does not. Addressing one bit means driving \(I_c/2\) on one X line and \(I_c/2\) on one Y line so only the intersection sees \(I_c\).

Readout is destructive: the READ pulse forces the core toward a known polarity. If the core was previously the opposite polarity, it flips and induces a millivolt-scale spike on the sense wire; if it was already that polarity, the spike is negligible. After sensing, a WRITE (restore) pulse returns the desired data, optionally with an INHIBIT current so a restore-to-0 does not flip the core back to 1.

For this plane, expect \(I_c\) in the 400–800 mA range (0.125″ cores), so regulated half-select is about 200–400 mA. See [design_spec.md](design_spec.md) for the normative numbers. A separate ngspice model of one 50-mil toroid, and how its sense pulse compares with the published read-1, is in [core_element_sim.md](core_element_sim.md).

## Three wires per core (no inhibit winding)

Each ferrite core is threaded by exactly **three** wires:

| Wire | Count on plane | Role |
|---|---|---|
| **X** | 64 lines | Half-select address |
| **Y** | 64 lines | Half-select address |
| **Sense** | Two independent loops, 2,048 cores each | READ pickup **and** WRITE-0 inhibit |

This is classic 3-wire core memory: there is **no fourth inhibit winding**. Inhibit current is **time-multiplexed onto the sense wire** (high current during WRITE/RESTORE 0; quiet differential sensing during READ). The plane does not join the two loops. The driver board ties them in series. Outer ends are `YA65`/`YB66`; the center tap is `YA66`═`YB65`.

## Dual sense / inhibit loops

The plane has no separate sense connector beyond pins 65/66 on the Y edges. Those four terminals are two **independent** 3-wire loops. Vintage 4K planes split the sense/inhibit winding this way so each loop has about half the inductance, DC resistance, and transmission delay of one weave through all 4,096 cores. No numeric L or DCR is recorded here; each loop is half of that former single-weave estimate. Series connection on the driver presents the sum, which is the old full-array L and DCR.

| Loop | Path through cores | Ends |
|---|---|---|
| **Loop A** | 2,048 cores (geographic split untraced) | `YA65` ↔ `YA66` |
| **Loop B** | The other 2,048 cores | `YB65` ↔ `YB66` |

**External fold:** the driver ties `YA66` directly to `YB65`. That center-tap jumper is not on the plane. The full series sense/inhibit path is:

```text
YA65 ── Loop A (2048) ── YA66 ════ YB65 ── Loop B (2048) ── YB66
                              │
                         R1 10k → AGND   (soft ground at the center tap)
```

- **READ:** Differential sense across the outer ends `YA65` / `YB66` (1 kΩ isolation into `SENSE_P` / `SENSE_N`).
- **INHIBIT:** Source \(V_{drive}\) into `YA65`, traverse Loop A, cross the `YA66`═`YB65` jumper, traverse Loop B, and sink `YB66` into `CCS_INH`. Series \(-I_c/2\) puts all 4,096 cores in one string. Because the halves are in series, \(V_{drive}\) headroom and the inhibit sink stay at the single-weave values. X and Y each have their own sink (`CCS_X`, `CCS_Y`) so coincident half-select is \(I_c/2\) on each axis.
- **Soft ground:** 10 kΩ from the center tap (`YA66`/`YB65`) → AGND, not a hard AGND short, so inhibit current continues through Loop B into the CCS instead of dumping at the mid.

The schematic array is the 64×64 on the Magnetic Cores sheet ([`magnetic_core_64x64.kicad_sch`](../kicad/core/magnetic_core_64x64.kicad_sch)). Each X line runs top to bottom and each Y line right to left. The sense split is the 2×2 rule scaled, not a trace of the plane: `(x+y)` even is Loop A (mirrored, diagonals `x−y`), `(x+y)` odd is Loop B (unmirrored, diagonals `x+y`). Both loops are 2,048 cores in series, joined at `YA66`═`YB65`. The archived 2×2 page is [reference/magnetic_core_2x2.kicad_sch](../kicad/core/reference/magnetic_core_2x2.kicad_sch): Loop A is `YA65`↔MCE11↔MCE00↔`YA66`, Loop B is `YB65`↔MCE10↔MCE01↔`YB66`. Plane photos: [img/](img/); sources in [references.md](references.md).

```mermaid
flowchart LR
  YA65[YA65] --> ArrayYA[Loop A 2048]
  ArrayYA --> YA66[YA66]
  YA66 --> Jumper["YA66 = YB65 center tap"]
  Jumper --> SoftMid["R1 10k to AGND"]
  Jumper --> YB65[YB65]
  YB65 --> ArrayYB[Loop B 2048]
  ArrayYB --> YB66[YB66]
  YA65 -.-> SenseAmp[Differential sense amp]
  YB66 -.-> SenseAmp
```

## Access cycle

Every access is a READ / RESTORE sequence. Software bit-banging on a general-purpose MCU is too jittery; the plan is deterministic sequencing from RP2040 PIO (or equivalent hardware state machine).

```mermaid
sequenceDiagram
  participant X as X matrix
  participant Y as Y matrix
  participant S as Sense latch
  participant I as Inhibit path
  participant CCS as Ic/2 CCS

  Note over X,CCS: READ phase
  X->>CCS: drive -Ic/2 on selected X
  Y->>CCS: drive -Ic/2 on selected Y
  Note over S: 300 ns into the READ flat
  S->>S: SENSE STROBE clocks comparator into 74AHC74

  alt restore or write 0
    I->>I: INHIBIT -Ic/2 on YA65 through fold to YB66
  end

  Note over X,CCS: WRITE phase
  X->>CCS: drive +Ic/2 on selected X
  Y->>CCS: drive +Ic/2 on selected Y
```

1. **READ** — Drive \(-I_c/2\) into the addressed X and Y lines (forward polarity for read). Only the selected core sees full \(I_c\).
2. **SENSE STROBE** — 300 ns into the READ flat, clock the D flip-flop that samples the TLV3501 comparator across the outer ends `YA65` / `YB66`. Earlier than that, the flip plateau is not up yet, and `DOUT` does not reach a logic 1.
3. **INHIBIT** — If writing or restoring a 0, drive \(-I_c/2\) from `YA65` through both loops and the `YA66`═`YB65` center tap, sinking at `YB66`, so the subsequent WRITE cannot flip that core to 1.
4. **WRITE** — Drive \(+I_c/2\) into the same X and Y lines (reverse polarity) to restore or write 1 when inhibit is off.

## Constant-current sink

X lines, Y lines, and the inhibit path each return through their own adjustable constant-current sink (`CCS_X`, `CCS_Y`, `CCS_INH`). Each holds \(I_c/2\) flat into its load. The CCS block is one sheet, called three times: TL431 reference, multi-turn trimpot, OPA192 feedback amp, IRLZ44N throttle MOSFET, and a 1 Ω sense resistor. Without regulation, pulse amplitude would wander with temperature, MOSFET Rds(on), and wiring resistance, corrupting half-select margins. One shared return cannot supply X and Y together; the two lines would split the current and stay under \(H_c\).

## Timing controller

Sub-microsecond edges and fixed delays (strobe window, inhibit overlap, write width) need cycle-accurate hardware. The design targets Raspberry Pi Pico / RP2040 PIO blocks driven by tight C or assembly, independent of the main CPU’s interrupt load. Firmware is out of scope for this document set; the electrical contract is in [design_spec.md](design_spec.md) §5.

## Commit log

2026-10-02 Add the driver design and KiCad project.
    The docs and schematic are the source for the 1x1 prototype.
    [core.kicad_pcb, core.kicad_sch]
2026-10-02 logical schematic blocks reorg
    [core.kicad_sch]
2026-10-03 Split the schematic into hierarchical blocks and document the net grammar.
    [ccs.kicad_sch, core.kicad_sch, decode_block.kicad_sch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]
2026-10-03 core-element simulation plus research
    [core_element_sim.kicad_sch, ferrite_beads.kicad_sch]
2026-10-03 created new component based on simulation and replace resistive model with inductive model
    [core.kicad_sch, ferrite_beads.kicad_sch]
2026-10-03 Docs updated to match physical core layout.
    [core.kicad_sch, core_element_sim.kicad_sch, ferrite_beads.kicad_sch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]
2026-10-04 Prove the 2×2 access cycle from the address pins through decode, drive, and the sense latch.
    Three current sinks, the diode matrix, and drive groups 0--7 are on the schematic. The four-core decks are the gate; weave inductance is still an open input.
    [ccs.kicad_sch, core.kicad_sch, decode_block.kicad_sch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]
2026-10-04 renamed to magnetic_core_2x2
    [core.kicad_sch, magnetic_core_2x2.kicad_sch]
2026-10-04 Scaled to 64x64 and paying heavy due. We can learn if we have to... I guess.
    [core.kicad_sch, drive_block.kicad_sch, magnetic_core_2x2.kicad_sch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]
